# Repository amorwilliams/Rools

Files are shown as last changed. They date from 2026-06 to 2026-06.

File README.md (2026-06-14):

# Rools

10HP+2HP 可选扩展 Eurorack 多功能可视化 DSP 模块。Daisy Seed + 1.77" 横屏 IPS，单 App 运行模式。

## 文档索引

| 文档 | 说明 |
|---|---|
| [docs/00-overview.md](docs/00-overview.md) | 项目概述 |
| [docs/01-product-spec.md](docs/01-product-spec.md) | 产品规格 |
| [docs/02-panel-layout.md](docs/02-panel-layout.md) | 面板布局 |
| [docs/03-io-spec.md](docs/03-io-spec.md) | I/O 定义 |
| [docs/04-hardware-architecture.md](docs/04-hardware-architecture.md) | 硬件架构 |
| [docs/05-software-architecture.md](docs/05-software-architecture.md) | 软件架构 |
| [docs/06-ui-ux.md](docs/06-ui-ux.md) | 交互规范 |
| [docs/07-roadmap.md](docs/07-roadmap.md) | 开发里程碑 |
| [docs/08-app-switching.md](docs/08-app-switching.md) | App 丝滑切换 |
| [docs/decisions/](docs/decisions/) | ADR 决策记录（含电源/显示/机械） |
| [docs/references/modules-comparison.md](docs/references/modules-comparison.md) | 参考模块对比 |

## 快速开始

```bash
git clone --recursive <repo>
./build.sh          # 编译
./build.sh flash    # 刷机（Seed DFU 模式）
```

详见 [firmware/README.md](firmware/README.md)。

## 依赖版本（git submodule，固定 tag）

| 库 | Tag | Commit |
|----|-----|---|
| [libDaisy](https://github.com/electro-smith/libDaisy) | **v8.1.0** | `9498417` |
| [DaisySP](https://github.com/electro-smith/DaisySP) | **V1.0.0** | `a0494a3` |

克隆务必带 submodule：`git clone --recursive`。升级依赖时在 `lib/` 内 checkout 新 tag，编译验证后 commit 父仓库的 submodule 指针。

## 目录结构

```
Rools/
├── lib/            # libDaisy / DaisySP submodule
├── docs/           # 设计文档
├── hardware/       # 面板规格、BOM（KiCad 后续）
├── firmware/       # libDaisy 固件
└── build.sh        # 编译脚本
```

## 参考

- [Daisy Seed](https://daisy.audio/hardware/Seed/)
- [O_C 4.1 O.R.N.8](https://modulargrid.net/e/tunefish-modular-ornament-crime-o-c-t4-1-o-r-n-8)

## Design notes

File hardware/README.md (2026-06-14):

# hardware/

## 子目录

| 路径 | 内容 |
|---|---|
| [kicad/rools-core/](kicad/rools-core/) | **M2** KiCad 工程（10HP Core） |
| [panel/rools-core-10hp-spec.md](panel/rools-core-10hp-spec.md) | 10HP 面板开孔/丝印 |
| [panel/rools-exp-2hp-spec.md](panel/rools-exp-2hp-spec.md) | 2HP Exp 面板 |
| [bom/bom-draft.md](bom/bom-draft.md) | 初步 BOM |

## KiCad

打开 `hardware/kicad/rools-core/rools-core.kicad_pro`（KiCad 10.x）。

层次：`Power` / `Seed` / `Audio` / `CV` / `UI` — 不含 Exp（USB/MIDI）。

音频/电源对照 Daisy Patch Rev8，见 [kicad/rools-core/docs/patch-reference.md](kicad/rools-core/docs/patch-reference.md)。

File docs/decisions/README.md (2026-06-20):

# ADR 索引

Architecture Decision Records — 记录已确认的设计决策。

| ID | 标题 | 状态 |
|----|---|---|
| [ADR-001](ADR-001-single-app-mode.md) | 单 App 运行模式 | 已接受 |
| [ADR-002](ADR-002-display-choice.md) | 1.77" 横屏 IPS | 已接受 |
| [ADR-003](ADR-003-io-topology-10hp-exp.md) | 10HP + 2HP Exp 拓扑 | 已接受 |
| [ADR-004](ADR-004-ac-dc-coupling.md) | AC/DC 耦合策略 | 已接受 |
| [ADR-006](ADR-006-ext-4ch-dac.md) | 外置 4ch DAC | 已接受 |
| [ADR-007](ADR-007-usb-a-host-storage.md) | USB-A Host 存储 | 已接受 |
| [ADR-008](ADR-008-usb-ota-updater.md) | USB OTA 固件更新 | 已接受 |
| [ADR-009](ADR-009-center-button.md) | 双 Enc 中间单键 | 已接受 |
| [ADR-010](ADR-010-mono-stereo-normaling.md) | Mono/Stereo 与 Normalled | 已接受 |
| [ADR-011](ADR-011-power-supply.md) | 内部 Buck 电源与 USB 限流 | 已接受 |
| [ADR-012](ADR-012-display-spi-dma.md) | 显示 SPI DMA 与局部刷新 | 已接受 |
| [ADR-013](ADR-013-mechanical-depth.md) | 模块深度与机械布局 | 已接受 |
| [ADR-014](ADR-014-pcb-4-layer.md) | 4 层 PCB 叠层与分区 | 已接受 |
| [ADR-015](ADR-015-settings-persistence.md) | 设置持久化与 Flash 磨损策略 | 已接受 |
| [ADR-016](ADR-016-onboard-audio-no-pcm3060.md) | 板载音频（无 PCM3060） | 已接受 |
| [ADR-017](ADR-017-split-adc-knob-cv-sum.md) | CV/Knob 分路 ADC + 软件合成 | 已接受 |

## 如何新增 ADR

1. 复制模板：`ADR-XXX-简短标题.md`
2. 填写 Context / Decision / Consequences
3. 更新本索引

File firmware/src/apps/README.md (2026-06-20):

# App 开发规范

## 新增 App 步骤

1. 在 `apps/` 下创建 `my_app.h` / `my_app.cpp`
2. 继承 `rools::App`，实现全部纯虚函数
3. 在 `main.cpp`（或 `app_registry.cpp`）注册到 `AppShell`
4. 定义 `ParamMap` 标签（K1–K4 列语义）

## 示例骨架

```cpp
class SpectrumApp : public rools::App {
public:
    const char* name() const override { return "Spectrum"; }

    void on_enter() override {}
    void on_exit() override {}

    void audio_callback(const float* inL, const float* inR,
                        float* outL, float* outR, size_t n) override {
        // FFT / passthrough
    }

    void ui_draw() override {}

    const ParamMap* param_map() const override {
        static ParamMap m{"Gain", "Decay", "FFT Size", "Peak Hold"};
        return &m;
    }

    CouplingMode in_coupling() const override { return CouplingMode::DC; }
};
```

## 约束

- `audio_callback` 必须实时安全：无 malloc、无 blocking IO
- UI 在 `ui_draw` 或主循环低优先级刷新，目标 30 fps
- 读 `AppShell::columns[i].knob / .cv / .sum`（列语义由本 App 定义；见 `board/cv_reference.*`）
- 写 `AppShell::cv_out` 设置 CV A–D（由 shell 送 DAC）

## App 切换（MFX 式）

设计文档：[docs/08-app-switching.md](../../docs/08-app-switching.md)

| API | 线程 | 说明 |
|-----|---|---|
| `request_app_switch(i)` | UI | 运行时切换（TODO M3 fade） |
| `load_app(i)` | 任意 | 立即切换，仅 boot / 调试 |
| `uses_shared_dsp_memory()` | — | FX App 使用 `dsp_pool()` 时覆写 |
| `on_release_shared_memory()` | 音频 | pool Reset 前清尾音 |

```cpp
// TODO(M3) DelayApp 示例
bool uses_shared_dsp_memory() const override { return true; }
void on_release_shared_memory() override { /* 丢弃 delay 状态 */ }
```

## 路线图 App

| 文件（计划） | App |
|---|-----|
| `spectrum_app.*` | P0 |
| `oscilloscope_app.*` | P0 |
| `lissajous_app.*` | P1 |
| `delay_app.*` | P1 |
| `reverb_app.*` | P1 |
| `granular_app.*` | P2 |

## USB 依赖

Granular 等需 `HAS_EXP` 与 `UsbStorage`；无 U 盘时使用 Flash factory 样本。

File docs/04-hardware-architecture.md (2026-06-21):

# 04 — 硬件架构

## 系统框图

```
Front Panel (10HP)
├── 1.77" IPS ST7735 ── SPI ──► Daisy Seed
├── Enc A/B + Btn ────────────► GPIO
├── K1–K4 ──► MCP6004 ──► ADC4–7 (Knob)
├── CV1–4 Jacks ──► MCP6004 ──► ADC0–3 (CV)
├── CV A–D Jacks ◄── OPA4171 ◄── DAC8565 ◄── SPI1
└── IN/OUT Audio ──► TL074 ±10V ──► Seed pin 16–19 (板载 Codec)

Exp Panel (+2HP)
├── MIDI IN/OUT — USART1（D13/D14，Seed pin 14/15）→ P2 pin 7/8
└── USB-A Host ── OTG (D29–30, D0 ID) ──► P2 `+5V` + Exp 本地 VBUS 限流

Power: Eurorack ±12V → **Buck +5V** → Seed / Display / USB VBUS（限流）
       详见 [ADR-011](decisions/ADR-011-power-supply.md)
```

## 音频路径（无 PCM3060）

Eurorack jack ↔ **TL074**（×0.1 入 / ×10 出）↔ Seed **AUDIO_IN/OUT_L/R**（pin 16–19，板载 WM8731）。详见 [ADR-016](decisions/ADR-016-onboard-audio-no-pcm3060.md)。

## IN_R Normalled

IN_R jack **normalize 到 IN_L**，KiCad 网 **`IN_L_NORM`**（`J_CV_5` Tip ↔ `J_CV_6` Switch）。空插 R 时右声道 = 左声道。

接法详见 [ADR-010](decisions/ADR-010-mono-stereo-normaling.md)。

## Daisy Seed 引脚预算（2026-06 定稿）

**左侧 pin 1–19**

| 功能 | Daisy | Seed pin |
|---|---|---|
| Exp `EXP_GPIO0` | D0 | 1 | `USB_HS_ID` → P2 pin 15 |
| Enc A A/B/Sw | D1–D3 | 2–4 |
| Btn | D4 | 5 |
| 显示屏 SPI | D5–D10 | 6–11 | D8/D10 与 DAC8565 共用 |
| Exp I2C1 | D11–D12 | 12–13 | `I2C_SCL` / `I2C_SDA` → P2 pin 13/14 |
| Exp MIDI | D13–D14 | 14–15 | `MIDI_TX` / `MIDI_RX`（USART1）→ P2 pin 7/8 |
| Audio L/R In/Out | — | 16–19 |

**右侧 pin 22–32**

| 功能 | Daisy | Seed pin | ADC |
|---|---|---|-----|
| CV1–4 | D15–D18 | 22–25 | 0–3 |
| KNOB1–4 | D19–D22 | 26–29 | 4–7 |
| Enc B A/B/Sw | D23–D25 | 30–32 | — |
| DAC8565 | D26–D27 | 33–34 | `DAC_CS` / `DAC_LDAC` |
| 掉电检测 | D28 | 35 | net `EXTI_PWR` ← LM393（ADR-015） |

## ADC 分配

| 通道 | 用途 |
|---|---|
| ADC 0–3 | CV1–CV4（jack） |
| ADC 4–7 | KNOB1–K4 |
| ADC 8+ | — | D28 作掉电检测 GPIO，非 ADC 用途 |

固件在 AudioCallback 合成 `ControlColumn.sum`（[ADR-017](decisions/ADR-017-split-adc-knob-cv-sum.md)）。

## DAC

| 来源 | 用途 |
|---|---|
| DAC8565 ×4 | CV Out A–D（内部 2.5V 基准 → OPA4171 0–2.5V → ±10V；R 12.5k/100k 0.1%） |
| Seed 内置 DAC ×2 | v1 闲置 |

## P2 EXP_BUS（2×8，Core ↔ Exp）

| Pin | 信号 | 说明 |
|-----|---|---|
| 1 | `+3V3_D` | 数字域 |
| 2 | `+3V3_A` | Seed 模拟域（MIDI 光耦等） |
| 3 | `SWDIO` | 与 P3 并联，Exp 侧可选接 |
| 4 | `SWCLK` | |
| 5 | `RESET` | |
| 6 | `GND` | |
| 7 | `MIDI_TX` | D13 / Seed pin 14（USART1_TX） |
| 8 | `MIDI_RX` | D14 / Seed pin 15（USART1_RX） |
| 9 | `USB_D-` | D29 |
| 10 | `USB_D+` | D30 |
| 11 | `+5V` | Buck 输出；Exp USB Host 本地限流开关 |
| 12 | `GND` | |
| 13 | `I2C_SCL` | D11；Core 侧 4.7k→`+3V3_D` |
| 14 | `I2C_SDA` | D12 |
| 15 | `EXP_GPIO0` | D0 / `USB_HS_ID`；Exp Host 模式接 GND |
| 16 | `GND` | |

## 掉电检测

`+12V` → R43/R64 分压 → **LM393 U10A**（基准 `+3V3_D`）→ net **`EXTI_PWR`** → Seed **D28**。`+12V_SAFE`（D3 + C36/C37 ~2000 µF）维持 hold-up。阈值 ~10.6 V；固件 1 kHz 采样 debounce（连续 LOW ≥5 ms）→ 关背光 → Flash `Flush()`。详见 [ADR-015](decisions/ADR-015-settings-persistence.md)。

## 深度与机械

- 目标深度 **35 mm**（对齐 O_C 4.1）
- 1.77" 屏 + USB-A 为深度主要约束
- Core + Exp 同 PCB 侧出或 FFC 连接（KiCad 阶段定）
- 机械方案（Seed 贴片 / 沉板 USB / 矮排针）见 [ADR-013](decisions/ADR-013-mechanical-depth.md)

## PCB

- **4 层 / 1.6 mm**（[ADR-014](decisions/ADR-014-pcb-4-layer.md)）：L2 完整地、L3 电源；数字/模拟分区
- KiCad 工程后续置于 [hardware/](../hardware/)

## BOM 关键件（见 hardware/bom/bom-draft.md）

- Daisy Seed
- ST7735 1.77" IPS
- TL074 + MCP6004（音频/CV In 调理）
- DAC8565 + OPA4171（CV Out）
- USB-A 母座 + 5V Host 供电/限流（Exp）
- Thonkiconn 或 PJ398 插孔 ×12

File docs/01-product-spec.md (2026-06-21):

# 01 — 产品规格

## 外形

| 项目 | Rools Core | Rools Exp（可选） |
|---|---|---|
| 宽度 | 10 HP（~50.3 mm） | +2 HP（~10.16 mm） |
| 高度 | 3U（128.5 mm） | 同左 |
| 深度 | 目标 35–40 mm | 同核心 PCB |
| PCB | **4 层 1.6 mm** | [ADR-014](decisions/ADR-014-pcb-4-layer.md) |
| 面板 | 2 mm 阳极氧化铝 | 同左 |

## 显示

| 项目 | 规格 |
|---|---|
| 尺寸 | 1.77" IPS TFT |
| 方向 | 横屏（Landscape） |
| 分辨率 | 160 × 128 |
| 驱动 | ST7735（SPI） |
| Outline | 34.0 × 43.8 mm |

## 控件

| 控件 | 数量 |
|---|---|
| Encoder + Push | 2（Enc A / Enc B） |
| 小按键（6 mm tact） | 1（Enc 中间） |
| Potentiometer | 4（K1–K4） |

## I/O 汇总

| 类型 | 数量 |
|---|---|
| CV In | 4（CV1–CV4，DC）+ 4 Knob（K1–K4）分路 ADC，固件合成 |
| CV Out | 4（A–D，DAC8565 + OPA4171） |
| Audio In | 2（IN_L / IN_R，AC/DC 可选） |
| Audio Out | 2（OUT_L / OUT_R，AC/DC 可选） |
| MIDI | IN + OUT（Exp） |
| USB-A Host | 1（Exp） |

## 电气（预估，待实测）

| 项目 | 预估值 |
|---|---|
| +12V | 150–200 mA（Core）；+50–100 mA（Exp USB Host） |
| -12V | Seed 板载音频负轨（TL074 ±10V 调理） |
| +5V | **模块内部 Buck 自 +12V 产生**（不用机箱 +5V；禁线性 7805 主路径） |

电流预算与 USB 限流见 [ADR-011](decisions/ADR-011-power-supply.md)。

## MCU

| 项目 | 规格 |
|---|---|
| 模块 | Daisy Seed |
| MCU | STM32H750，480 MHz |
| RAM | 64 MB SDRAM |
| Flash | 8 MB |
| 音频 | 48 kHz / 24-bit（Seed 板载 Codec + TL074，[ADR-016](decisions/ADR-016-onboard-audio-no-pcm3060.md)） |

## 功能路线图

| 优先级 | App |
|---|-----|
| P0 | Spectrum Analyzer、Oscilloscope |
| P1 | Lissajous、Delay、Reverb |
| P2 | Granular、Envelope Follower |

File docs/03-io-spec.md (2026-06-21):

# 03 — I/O 规格

## 拓扑

**Core**：6 模拟输入（4 CV + 2 Audio）+ 6 模拟输出（4 CV + 2 Audio）  
**Exp**：MIDI ×2 + USB-A Host

## CV 输入（CV1–CV4）

| 项目 | 规格 |
|---|---|
| 方向 | 输入 |
| 耦合 | DC 固定 |
| 电压 | Eurorack ±10V（调理至 ADC 量程） |
| Knob | K1–K4 **分路 ADC**（D19–D22）；`sum` 固件合成（[ADR-017](decisions/ADR-017-split-adc-knob-cv-sum.md)） |
| 默认语义 | K1/K2 主参数；K3 Clock；K4 Trig（App 可重映射） |

## CV 输出（A–D）

| 项目 | 规格 |
|---|---|
| 方向 | 输出 |
| 耦合 | DC 固定 |
| 硬件 | DAC8565（SPI，4× 16-bit，内部 2.5V 基准）+ OPA4171 0–2.5V→±10V |
| 用途 | LFO / 包络 / Trig / Gate CV（App 分配） |

## 音频输入（IN_L / IN_R）

| 项目 | 规格 |
|---|---|
| 方向 | 输入 |
| 耦合 | 硬件 DC；软件 AC/DC 可选 |
| 电压 | Eurorack ±10V |
| **Mono** | **IN_R normalled 到 IN_L**（R 孔空 = R 通道 = L） |
| Codec | **Seed 板载**（pin 16–19）+ TL074 ±10V |

## 音频输出（OUT_L / OUT_R）

| 项目 | 规格 |
|---|---|
| 方向 | 输出 |
| 耦合 | 硬件 DC；软件 AC/DC 可选 |
| **Mono→立体声** | 软件 `out_R = out_L` |
| 菜单 | Input: Auto / Mono / Stereo；Output: Stereo / Mono(L→R) |

## 立体声 / Mono 实现分层

| 环节 | 层 | 做法 |
|---|-----|---|
| 只插 IN_L | 硬件 | IN_R normalled → IN_L |
| L 复制到 OUT_R | 软件 DSP | AudioEngine callback |

## Exp — MIDI

| 项目 | 规格 |
|---|---|
| 接口 | MIDI IN / OUT |
| 物理 | 3.5 mm TRS 或 DIN（待定） |
| 协议 | UART |

## Exp — USB-A Host

| 功能 | 路径 |
|---|---|
| 样本 | `/rools/samples/` |
| 预设 | `/rools/presets/` |
| Scene | `/rools/scenes/` |
| 固件 OTA | `/rools/_updater/*.bin` → 刷完删除，写 `update.log` |

## AC/DC 切换范围

| 接口 | 软件 AC/DC |
|---|---|
| IN_L / IN_R | ✅ |
| OUT_L / OUT_R | ✅ |
| CV1–CV4 | ❌ DC 固定 |
| CV A–D | ❌ DC 固定 |

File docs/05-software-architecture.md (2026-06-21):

# 05 — 软件架构

## 技术栈

- [libDaisy](https://daisy.audio/software/) + DaisySP
- C++17
- 48 kHz stereo audio callback（float，Seed 板载 24-bit）

## 单 App 模式

```
Boot → AppShell → AppMenu → [当前 App]
                              ↓
                    on_enter / process / on_exit
```

切换：Enc A 长按 → 选 App → 确认 → **~10 ms crossfade** → 新 App `on_enter()`。

丝滑切换设计详见 **[08-app-switching.md](08-app-switching.md)**（MFX 式：UI 递 flag、ISR fade、静态 DSP 池）。

## AppShell 职责

| 模块 | 职责 |
|---|---|
| AudioEngine | I/O、Mono 复制、AC/DC 高通、callback 分发 |
| UIRenderer | ST7735 菜单/波形/频谱；**SPI DMA + 局部刷新**（[ADR-012](decisions/ADR-012-display-spi-dma.md)） |
| IOMapper | 8 路 ADC（4 CV + 4 Knob）→ 4 列 `ControlColumn`（`knob`/`cv`/`sum` 软件合成） |
| CVRouter | CV A–D 输出分配 → `CvOutDriver`（DAC8565 SPI1 + LDAC） |
| ClockSync | CV3/CV4 边沿检测（App 可选） |
| UsbStorage | FAT32、样本/预设/OTA（HAS_EXP） |
| SettingsStore | `GlobalSettings` QSPI 环缓持久化；见 [ADR-015](decisions/ADR-015-settings-persistence.md) |

## 设置持久化

- `SettingsStore`：`Init` 读环缓 / 迁移旧格式 → RAM；`MarkDirty` + `Tick` 节流落盘；`Flush` 强制写
- CV 校准、切 App 等关键路径显式 `Flush`
- 掉电保存：D28 1 kHz debounce → 关背光 → `OnPowerFail()` / `Flush()`（[ADR-015](decisions/ADR-015-settings-persistence.md)）

## 输入采集约束（必须遵守）

- Encoder / Switch 的 `Debounce()` 必须在固定频率中断里执行（当前用 `AudioCallback`）。
- 中断里只做采集与累计：读取 `Increment()` 并累加到共享计数器，记录按下/抬起事件位。
- 主循环只做消费：原子读取并清零累计值，再分发到 `on_enc / on_btn`。
- 禁止在 UI 主循环里直接 `Debounce()`；SPI 刷屏会阻塞主循环，导致漏采样和手感变差。

## App 接口（见 firmware/src/app_shell.h）

```cpp
class App {
  virtual void on_enter() = 0;
  virtual void on_exit() = 0;
  virtual void audio_callback(float* inL, float* inR,
                              float* outL, float* outR, size_t n) = 0;
  virtual void ui_draw() = 0;
  virtual void on_encoder(Enc enc, int delta) {}
  virtual void on_button(Button btn) {}
  virtual const ParamMap* params() const = 0;
};
```

## 音频流

```
Seed onboard In (L,R) → [耦合/Mono] → App::audio_callback → [耦合/Mono out] → Seed onboard Out
                                      ↑
                              columns[0..3] knob/cv/sum（控制率，AudioCallback 更新）
```

## USB 目录（Exp）

```
/rools/
├── samples/
├── presets/
├── scenes/
├── _updater/     # rools_firmware.bin, update.log
└── README.html   # v2
```

## 条件编译

| 宏 | 含义 |
|----|---|
| `HAS_EXP` | 装 Exp：MIDI + USB Host |
| `HAS_USB` | 同 HAS_EXP |

## App 路线图

| 优先级 | App | 类型 |
|---|-----|---|
| P0 | SpectrumAnalyzer | 可视化 |
| P0 | Oscilloscope | 可视化 |
| P1 | Lissajous | 可视化 |
| P1 | Delay, Reverb | FX |
| P2 | Granular, EnvelopeFollower | FX / 工具 |

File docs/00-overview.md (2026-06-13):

# 00 — 项目概述

## 是什么

**Rools** 是一款 Eurorack 多功能模块：

- **10HP 核心**：大屏频谱/波形可视化 + DSP 效果器平台
- **+2HP 可选扩展**：MIDI + USB-A Host（样本/预设/固件更新）
- **MCU**：Electrosmith [Daisy Seed](https://daisy.audio/software/)

## 设计目标

1. **可视化优先** — 1.77" IPS 横屏，频谱/示波/李萨如
2. **平台化** — 统一 UI/I/O，单 App 模式增量扩展功能
3. **紧凑** — 10HP 核心对标 O_C 功能面宽度，大屏差异化

## 参考模块

| 模块 | 借鉴 |
|---|---|
| [O'Tools Plus](https://www.jonesvideo.com/otool/Otool_Plus_UserManual.pdf) | 测量/可视化 |
| [ALM MFX](https://www.busycircuits.com/alm017/) | 立体声 DSP FX |
| [O_C 4.1](https://modulargrid.net/e/tunefish-modular-ornament-crime-o-c-t4-1-o-r-n-8) | 10HP+2HP 架构、双 Encoder |
| [Instruō arbhar / Lúbadh](https://www.instruomodular.com/firmware/) | USB 样本/预设/OTA |

## 运行模式

**单 App**：一次运行一个功能（Spectrum / Delay / …），切换需退出当前 App。

## 术语

| 术语 | 含义 |
|---|---|
| HP | Horizontal Pitch，1 HP = 5.08 mm（面板宽约 50.3 mm @ 10HP） |
| CV | Control Voltage，控制电压 |
| Normalled | 插孔未接线时内部连通到另一孔（如 IN_R → IN_L） |
| App | 固件内一个独立功能模块 |

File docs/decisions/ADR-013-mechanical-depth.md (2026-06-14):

# ADR-013: 模块深度与机械布局

## 状态

已接受

## 背景

目标深度 **35–40 mm**（对齐 O_C 4.1）。主要堆叠：

- 前面板（2 mm Alu）+ 控件轴长
- 1.77" TFT + FPC/排针
- Daisy Seed（排母插接很占 Z 高度）
- Eurorack 插孔（Thonkiconn 筒深）
- Exp：**USB-A 母座** 为最大深度约束之一

## 决策

KiCad 阶段在以下方案中 **选最薄可行组合**（可混合）：

| 约束 | 优先方案 | 备选 |
|---|---|---|
| Daisy Seed | **贴片焊接** 于主 PCB（最薄） | 1.27 mm 矮排针 + 无排母直插 |
| Seed 可维护性 | 若必须可拆：矮排母 + 侧面留测试点 | 牺牲 3–5 mm |
| USB-A（Exp） | **沉板式** 母座 或 **垂直子板**（Exp PCB 90° 相对 Core） | 标准竖插母座（最深，尽量避免） |
| 屏 | 排针/FPC 贴 PCB，背光常亮或 GPIO 控 | — |
| Pot / Enc | 选 **薄型** 轴（9 mm pot 已选） | — |

**深度预算**：Layout 前建 Excel/mm 叠层表，合计 ≤ 38 mm（留 2 mm 公差）。

## 理由

- 35 mm 内排母 + 标准 USB-A + 标准 Seed 叠放几乎不可能
- O_C 4.1 同档深度是产品对标；超标则难进浅箱

## 后果

- 贴片 Seed 降低现场换 MCU 便利性；调试靠 SWD + USB Micro
- Exp 垂直子板可能影响面板 USB 开口机械；Gerber 前 3D 装配验证
- `04-hardware-architecture.md` 深度节引用本 ADR

## 待验证

- [ ] KiCad 3D：Core / Core+Exp 总深度
- [ ] 最短 Eurorack 电源线 + 模块同时插入机箱
- [ ] 面板开孔与 USB-A 对齐（Exp）

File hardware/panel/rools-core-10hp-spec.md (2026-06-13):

# Rools Core — 10HP 面板规格

## 外形

| 项目 | 值 |
|---|-----|
| 宽度 | 10 HP = 50.3 mm（Doepfer 实际宽度 ~50.0 mm） |
| 高度 | 128.5 mm |
| 厚度 | 2 mm 铝 |
| 安装孔 | 上下各 1× M3（8–10 HP 标准） |

## 开孔区（自上而下）

### 1. 显示屏窗口

| 项目 | 值 |
|---|-----|
| 模块 | 1.77" IPS ST7735 |
| Outline | 34.0 × 43.8 mm（横屏：宽 43.8，高 34） |
| 建议窗口 | 比 outline 大 0.5 mm/边 |
| 位置 | 水平居中，距顶 ~8 mm |

### 2. Encoder + 按钮行（~34 mm 以下）

| 件 | 数量 | 孔径/说明 |
|----|---|---|
| Rotary Encoder | 2 | 6 mm 轴；Enc A 列 2，Enc B 列 3 附近 |
| Tact Switch | 1 | 6 mm；两 Encoder 中间 |
| 行高 | ~14 mm | |

### 3. Potentiometer 行

| 件 | 数量 | 说明 |
|----|---|---|
| 9 mm 或 16 mm 轴 Knob | 4 | 与 CV1–4 列对齐；轴间距 ~12.5 mm |
| 行高 | ~16 mm | |

### 4. 插孔区（3 行 × 4 列）

| 行 | 标签（丝印） | 孔 |
|----|---|-----|
| 1 | CV IN: CV1 CV2 CV3 CV4 | 4× 3.5 mm |
| 2 | CV OUT: A B C D | 4× 3.5 mm |
| 3 | AUDIO: IN_L OUT_L IN_R OUT_R | 4× 3.5 mm |

- 孔型：Thonkiconn/PJ398 标准 7.8 mm 安装孔
- 列 pitch：~12.5 mm（50.3 mm 四等分减边距）
- 行 pitch：~9–10 mm

## 丝印

- 顶：ROOLS
- 分区：CV IN / CV OUT / AUDIO
- Enc A / Enc B 可选

## PCB 对位

- 面板与 PCB 用 2× M3 尼龙柱或直接 PCB 装孔对齐
- 深度预算：屏 + 编码器 + 竖插 jack ≈ 35 mm

## 待 KiCad 验证

- [ ] 4× Knob 9 mm 轴间距与帽干涉
- [ ] 1.77" 屏 bezel 与 Encoder 行垂直间距
- [ ] Mounting hole 与 jack 无干涉

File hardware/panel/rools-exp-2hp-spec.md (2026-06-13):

# Rools Exp — 2HP 面板规格

## 外形

| 项目 | 值 |
|---|-----|
| 宽度 | 2 HP = 10.16 mm（实际 ~10.0 mm） |
| 高度 | 128.5 mm |
| 厚度 | 2 mm 铝 |

## 开孔（自上而下）

| 序号 | 件 | 说明 |
|---|-----|---|
| 1 | MIDI IN | 3.5 mm TRS 或 2× DIN（待定） |
| 2 | MIDI OUT | 同左 |
| 3 | USB-A 母座 | 垂直或 90° 出板；注意深度 |

## 丝印

- MIDI IN / MIDI OUT
- USB HOST

## 机械

- 与 Core PCB 同深度目标 35 mm
- USB-A 全尺寸为深度关键件；可选 90° 母座减深度
- Exp 与 Core 面板相邻安装，共享或 FFC 连接 Core PCB

## 电气连接

- Exp 不独立供电：排针/FFC 从 Core 取 5V Host 供电、MIDI UART、USB D+/D-

## 待定

- [ ] MIDI TRS Type A vs B 标注
- [ ] USB 母座型号（深度 vs 牢靠）

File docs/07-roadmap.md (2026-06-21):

# 07 — 开发里程碑

## 阶段总览

| 阶段 | 目标 | 产出 |
|---|---|---|
| **M0 设计** | 设计案 + 工程结构 | 本文档集 ✅ |
| **M1 原型** | Seed + 屏 + 音频 breadboard | Spectrum App 可运行 |
| **M2 面板** | PCB + 10HP Core（+可选 Exp） | 完整 I/O |
| **M3 FX** | Delay / Reverb App | 可演出 |
| **M4 抛光** | UI 动画、预设、校准 | v1.0 |

## M1 原型清单

- [x] Daisy Seed + libDaisy 工具链
- [x] ST7735 1.77" 横屏驱动（blocking SPI，M1 可接受）
- [ ] 外置 Codec breadboard（或 Patch 子板参考）
- [ ] FFT 频谱显示 30 fps
- [x] Enc A/B + 单键 UI 框架

## M2 硬件清单

- [x] KiCad 原理图 Core 页（Power Rev 0.2 / CV / Audio / UI / Seed；[ADR-011](decisions/ADR-011-power-supply.md) Buck + 掉电检测）
- [ ] KiCad PCB Layout（[ADR-014](decisions/ADR-014-pcb-4-layer.md) **4 层**）
- [ ] 10HP 面板 Gerber（[ADR-013](decisions/ADR-013-mechanical-depth.md) 深度预算）
- [ ] 2HP Exp 面板（可选）
- [ ] DAC8565 CV Out 校准
- [ ] IN_R normalled 验证（[ADR-010](decisions/ADR-010-mono-stereo-normaling.md)）
- [ ] 功耗实测（Core / Core+Exp / USB U 盘）

## M2 软件清单

- [ ] **ST7735 SPI DMA + 局部刷新**（[ADR-012](decisions/ADR-012-display-spi-dma.md)，P0）

## M3 软件清单

- [ ] AppShell 完整实现
- [ ] **App 丝滑切换**（[08-app-switching.md](08-app-switching.md)：`request_app_switch`、fade、DspMemoryPool）
- [ ] App 菜单 UI（Enc A 长按）
- [ ] Delay / Reverb（DaisySP）
- [ ] 预设 JSON 读写（Flash）
- [ ] CV 列映射 API

## M4 清单

- [ ] USB Host + FAT32
- [ ] OTA `_updater` 流程
- [ ] Granular + 样本加载
- [ ] 出厂校准与测试脚本

## 风险跟踪

| 风险 | ADR | 阶段 |
|---|-----|---|
| +5V 发热 / USB 500 mA | [ADR-011](decisions/ADR-011-power-supply.md) | M2 PCB |
| SPI 阻塞拖慢 UI | [ADR-012](decisions/ADR-012-display-spi-dma.md) | M2 固件 |
| 深度超标 | [ADR-013](decisions/ADR-013-mechanical-depth.md) | M2 机械 |
| 2 层 PCB 噪声 / USB | [ADR-014](decisions/ADR-014-pcb-4-layer.md) | M2 Layout |
| Normalled 接错 | [ADR-010](decisions/ADR-010-mono-stereo-normaling.md) | M2 验证 |

另见 [docs/decisions/](decisions/) 与各文档「待验证」项。

## 版本命名

- 固件：`rools_firmware_vX.Y.Z.bin`
- 文档：随 Git 版本

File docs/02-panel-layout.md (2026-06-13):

# 02 — 面板布局

## Rools Core（10HP × 128.5 mm）v1.5

```
┌────────────────────────────────────────┐
│      1.77" IPS Landscape 160×128       │  ~34mm
├────────────────────────────────────────┤
│  Enc A+Push    [Btn]    Enc B+Push     │  ~14mm
├────────────────────────────────────────┤
│  (K1)      (K2)      (K3)      (K4)    │  ~16mm
├────────────────────────────────────────┤
│  CV IN:  CV1    CV2    CV3    CV4       │
│  CV OUT:  A      B      C      D        │
│  AUDIO: IN_L  OUT_L  IN_R  OUT_R        │
└────────────────────────────────────────┘
              ← 50.3mm (10HP) →
```

## 垂直对齐

| 列 | 1 | 2 | 3 | 4 |
|----|---|---|---|---|
| Knob | K1 | K2 | K3 | K4 |
| CV In | CV1 | CV2 | CV3 | CV4 |
| CV Out | A | B | C | D |
| Audio | IN_L | OUT_L | IN_R | OUT_R |

## Rools Exp（+2HP）

```
┌──────────┐
│ MIDI IN  │
│ MIDI OUT │
│ USB HOST │
└──────────┘
```

## 尺寸约束

| 项目 | 数值 |
|---|---|
| 10HP 面板宽 | ~50.3 mm |
| 1.77" 屏 outline 宽 | 43.8 mm（横屏） |
| 屏侧余量 | ~3 mm/侧（放不下 O_C 式屏侧小键） |
| 4 列插孔 pitch | ~12.5 mm |
| 接口区 | 3 行 × 4 列 = 12 孔 |
| 控件+屏+孔总高约 | ~97 mm（128.5 mm 内可行） |

## 与 O_C 对照

| O_C 4.1 | Rools |
|---|---|
| 小 OLED + 屏侧 A/B/X/Y | 1.77" 横屏 + 中间单键 |
| 双 Encoder | 双 Encoder + Push |
| 2× Knob | 4× Knob |
| CV IN 8 / CV OUT 8 | CV IN 4 / CV OUT 4 |
| AUDIO 底行 | 同序 IN_L OUT_L IN_R OUT_R |

## 丝印建议

- 分区标题：`CV IN` / `CV OUT` / `AUDIO`
- Audio 底行顺序与 O_C 一致，便于用户 muscle memory
- CV Out 标签 A–D（或 OUT A–D）

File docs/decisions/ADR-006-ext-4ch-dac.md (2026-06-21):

# ADR-006: 外置 4 通道 CV DAC

## 状态

已接受（2026-06 修订：MCP4728 → DAC8565）

## 背景

面板 CV Out A–D 共 4 路；Daisy Seed 仅 2 路 12-bit 内置 DAC。

## 决策

v1 采用 **DAC8565**（SPI，4× 16-bit）；**AVDD=`+3V3_DAC`**、**IOVDD=`+3V3_D`**（内部 2.5V 基准，VREFL→GND）；经 **OPA4171**（R=12.5k/100k，增益 −8）调理至 Eurorack ±10V（DAC 0–2.5V → jack +10V～−10V）。Seed 内置 DAC 闲置。

| 信号 | Seed GPIO | Seed pin | 网表 |
|---|---|---|---|
| SPI1_SCK | D8 | 10 | 与 ST7735 共用 |
| SPI1_MOSI | D10 | 11 | 与 ST7735 共用 |
| DAC_CS (SYNC) | D26 | 33 | `DAC_CS` |
| DAC_LDAC | D27 | 34 | `DAC_LDAC` |

D11–D12 → Exp I2C；D13–D14 → Exp MIDI（USART1）。

## 理由

- 16-bit 优于 12-bit MCP4728，利于 CV 精度
- 与 LCD 共用 SPI1，独立 CS/LDAC，不占 I2C
- OPA4171 低功耗四运放，单芯片覆盖 4 路输出调理

## 后果

- 固件 `CvOutDriver` SPI 写 + LDAC 脉冲同步四路
- 需 CV Out 校准流程

## 待验证

- [ ] 四路 0V / ±10V 实测（M2）
- [ ] LDAC 批量更新无通道错位

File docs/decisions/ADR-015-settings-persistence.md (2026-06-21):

# ADR-015: 设置持久化与 Flash 磨损策略

## 状态

已接受

## 背景

Rools 需在 QSPI Flash 中持久化：

- CV 逐通道校准 (`GlobalSettings.cv[4]`)
- 上次打开的 App (`last_app_index`)
- 未来各 App / 菜单参数

Flash 物理特性：**最小擦除粒度 4KB**。无论修改 1 字节还是整扇区，一次 `Save` 消耗 **1 次扇区擦写寿命**（约 10 万次/扇区，IS25LP080D）。

Daisy Seed 面包板阶段**无**掉电保持电容，拔电瞬间无法可靠落盘；M2 PCB 已画比较器 + hold-up 前端（见 §3）。

## 决策

### 1. 统一 `GlobalSettings` 聚合 + `SettingsStore`

- 单块 RAM 工作副本；`MarkDirty()` + 2s 节流 `Tick()` 自动落盘
- 切 App、CV 校准完成时 `Flush()` 立即落盘
- 实现见 `firmware/src/settings/settings_store.{h,cpp}`

### 2. QSPI 环形缓冲区磨损均衡（本期）

- **10 槽 × 4KB** 轮转写入，sequence 单调递增，开机取最大有效槽
- 理论寿命 ≈ **10 万次 × 10 = 100 万次**擦写
- 无变化时跳过写入（`settings == persisted`）
- 一次性迁移旧 `libDaisy PersistentStorage` 单槽格式

### 3. 掉电检测保存（M2 PCB + 固件 debounce）

Power 页（Rev 0.2）已画掉电前端，Seed **D28 / pin 35** 接 net **`EXTI_PWR`**：

| 硬件 | 件 / 参数 | 作用 |
|---|---|---|
| 比较器 | **U10A LM393** | +12V 分压（R43 22k / R64 10k）vs `+3V3_D` 基准；开漏输出 + R65 10k 上拉 |
| 触发阈值 | ~**10.6 V** | \(V_{trip} = 3.3 \times 32/10\)；正常 +12V 时分压 ≈ 3.75 V，`EXTI_PWR` 高 |
| 保持 | **D3 SS34** → `+12V_SAFE` + **C36/C37 各 1000 µF** | 共 ~2000 µF，维持 Buck/比较器/写 Flash 窗口 |
| MCU 输入 | D28（`EXTI_PWR`） | 持续 LOW 表示掉电预警 |

**软件**（`firmware/src/board/pwr_fail.{h,cpp}`）：

- **1 kHz 定时器 ISR** 读 D28；连续 LOW ≥ **5 ms** 才认定掉电（过滤毛刺；面包板 D28 未接时不触发）
- 确认掉电后顺序：**`EmergencyBacklightOff()`**（GPIO 关背光，~30–50 mA）→ **`SettingsStore::OnPowerFail()`** → `Flush()`
- 禁止 SPI 刷屏 / DMA / audio 阻塞
- `HasPowerFailHardware()` → `true`（无编译宏；面包板靠 debounce 不误触）

M2 启用后可切换 **PowerFailOnly** 策略：运行期仅改 RAM，每次开关机 1 次擦写，与环形缓冲可叠加。

### 4. 演进路径（非本期）

1. 环形缓冲（本期）
2. 掉电 debounce 保存（M2 PCB + hold-up，见 [ADR-011](ADR-011-power-supply.md)）
3. 可选外挂 FRAM（高频序列器等）

## M2 掉电保存 hardware / 软件 checklist

- [x] 掉电前端原理图（LM393 + hold-up，Power 页 Rev 0.2）
- [ ] 保持电容容量：\(C \geq I_{hold} \cdot \Delta t / \Delta V\)（hold 电流、目标维持 ms、允许压降）
- [ ] 比较器阈值实测：+12V 跌至 ~10.6 V 前触发，Buck 仍可供电
- [x] D28 / `EXTI_PWR` 接线（Seed 页）；D13/D14 = Exp MIDI USART1
- [x] 固件：1 kHz debounce + 关背光 + `Flush()`
- [ ] 与环形缓冲联调：掉电写下一槽，sequence 递增

## 后果

- 原型/DIY：环缓 + 节流足够（每天 100 次保存 ≈ 27 年量级）
- 面包板拔电可能丢失未 Flush 的 `last_app_index` 等（2s 窗口内）；无 hold-up 时掉电保存不可用
- 校准 App 已显式 `Flush()`

## 相关

- [ADR-011](ADR-011-power-supply.md) — 电源架构与 hold-up
- [05-software-architecture.md](../05-software-architecture.md) — AppShell / Settings 集成

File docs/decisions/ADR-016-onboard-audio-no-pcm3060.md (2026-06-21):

# ADR-016: 板载音频（无 PCM3060）

## 状态

已接受

## 背景

原计划参考 Daisy Patch 使用外置 PCM3060 + SAI2。Core 原理图定稿改为 **Seed 板载 Codec**（pin 16–19）+ **TL074** Eurorack ±10V 调理，不装 PCM3060。

## 决策

1. 音频 I/O 走 Seed **AUDIO_IN/OUT_L/R**（板载 WM8731 路径，libDaisy 默认 `StartAudio`）。
2. Eurorack jack ↔ TL074（×0.1 入 / ×10 出）↔ Seed 16–19。
3. **不**使用 SAI2 接外置 Codec；D26–D27 作 DAC8565 `DAC_CS`/`DAC_LDAC`（CV Out 走 SPI1）。
4. IN_R **normalled** 经 `IN_L_NORM` 网（见 [ADR-010](ADR-010-mono-stereo-normaling.md)）。

## 理由

- 少一颗 Codec，BOM/布局更简单
- Seed 48 kHz 板载路径与现有固件 `AudioHandle` 一致
- Patch 的 ±10V 运放调理仍适用

## 后果

- Eurorack **jack 侧** DC ±10V；Seed 引脚边界仍为 **AC 耦合**（见 [ADR-004](ADR-004-ac-dc-coupling.md)）
- 示波器绝对 DC 电压测量优先用 CV ADC，非音频口
- 文档/BOM 删除 PCM3060；`kAudioFullScaleVolts` 按 ±1.8V line level 标定

## 待验证

- [ ] 实机：音频电平与噪声（M2）
- [ ] IN_R 空插时 R 通道 = L（示波器）

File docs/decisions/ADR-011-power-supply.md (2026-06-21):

# ADR-011: 内部电源与 USB Host 供电

## 状态

已接受

## 背景

Rools Core + Exp 负载包括：

| 子系统 | 典型 +5V 电流（估） |
|---|---|
| Daisy Seed | ~80–120 mA |
| ST7735 背光 | ~30–50 mA |
| 外置 Codec + 运放 | ~30–60 mA |
| DAC8565 + OPA4171 CV Out | ~10–20 mA |
| USB-A Host（U 盘） | ~50–100 mA 典型；规范上限 **500 mA** |

Eurorack 机箱 **+5V 轨往往很弱或不存在**；模块必须从 **+12V（及必要时 -12V）** 自产 +5V / +3.3V。

线性稳压（7805、LM1117 等）从 +12V 降压到 +5V：压差 ~7V × 300mA ≈ **2W+ 发热**，10HP 模块会烫手且不稳定。

## 决策

1. **+5V / +3.3V 一律用开关降压（Buck）**，禁止 7805 / LM1117 作为主 +5V 路径。
2. **不从 Eurorack 面板 +5V 取电**（若机箱有也仅作备用/debug，不纳入设计）。
3. **+12V 入口**：DC-DC Buck → +5V 母线 → Seed / 屏 / Codec 数字 / USB VBUS 开关。
4. **USB Host**：独立 **限流开关**（如 TPS20xx / AP2553 类，500 mA 可配置），带故障指示；U 盘未插时不向 VBUS 供电。
5. KiCad 阶段做 **电流预算表** 并留 **≥30% 裕量**；Exp 未装时 Core 单独测功耗。

### 参考器件（KiCad Power 页 Rev 0.2）

| 功能 | 器件 / 参数 |
|---|---|
| +12V → +5V | **TPS54302** Buck；FB R4=73.2 k / R2=10 k → **5.0 V** |
| +5V → +3.3V | **AP2112K-3.3** LDO → `+3V3_D` |
| DAC 模拟 | `+3V3_D` → 磁珠 → **`+3V3_DAC`**（DAC8565 AVDD） |
| 掉电 hold-up | **D3 SS34**：`+12V` → `+12V_SAFE`；**C36+C37** 各 1000 µF（共 ~2000 µF） |
| 掉电预警 | **LM393 U10A**：+12V 分压 vs `+3V3_D` → `EXTI_PWR` → Seed D28；阈值 ~10.6 V |
| USB VBUS | 限流 High-side switch + ESD |

掉电保存软件见 [ADR-015](ADR-015-settings-persistence.md)；Flush 前先 GPIO 关 ST7735 背光以节省 hold-up 电流。

## 理由

- 与 Daisy Patch / 商用 Eurorack 数字模块惯例一致
- USB Host 500 mA 峰值必须在 PCB 级可控，不能靠 Seed 裸供电
- 热设计在 35 mm 深度内无散热片空间

## 后果

- BOM 成本略高于线性方案；布局需 Buck 电感 + 足够铜皮
- `01-product-spec` 电流预估值须 M2 实测修订
- 见 [hardware/bom/bom-draft.md](../../hardware/bom/bom-draft.md) 电源行

## 待验证

- [ ] Core-only / Core+Exp 满载 +12V 电流（示波器 + 万用表）
- [ ] U 盘插入浪涌与 Buck 跌落
- [ ] 连续运行 30 min 外壳温升

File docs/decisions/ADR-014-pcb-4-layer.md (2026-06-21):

# ADR-014: 4 层 PCB 叠层与分区

## 状态

已接受

## 背景

Rools Core（+ 可选 Exp）单块或叠板 PCB 同时包含：

- **数字**：Daisy Seed（STM32H7）、ST7735 SPI、DAC8565 SPI、USB OTG Host、MIDI UART
- **模拟**：Eurorack ±10V 音频 In/Out、4× CV In/Out + 运放调理
- **电源**：[ADR-011](ADR-011-power-supply.md) Buck 开关降压（开关噪声、大电流回流）

2 层板无完整地平面，数字/模拟/电源难以分区；Buck 与 Codec/CV 邻域时易出现 hum、CV 噪声、USB 不稳定。同类模块（Daisy Patch、O_C、MFX）量产多采用 **4 层**。

10HP（~50 mm）布线密度高：12× 3.5 mm jack + 屏 + Seed + 电源，2 层需大量跳线式地线，layout 与调试成本高。

## 决策

1. **M2 正式 PCB 打样采用 4 层**，标准厚度 **1.6 mm**（不增加 [ADR-013](ADR-013-mechanical-depth.md) 深度预算）。
2. **不推荐 2 层作为量产方案**；仅当单块极低成本 Core-only 原型且接受更长调试周期时可例外。
3. **推荐叠层**（JLC / 常见 4L1.6 mm 工艺）：

| 层 | 用途 |
|----|---|
| L1（Top） | 元件面：Seed、Buck、屏接口、数字连接器；模拟 jack 靠板边 |
| L2 | **完整地平面 GND**（尽量不分割） |
| L3 | **+5V / +3.3V 铺铜** + 少量信号；Buck 输入/输出短路径 |
| L4（Bottom） | 信号、Eurorack 16-pin 电源、部分插孔 |

4. **分区原则**：
   - Buck、Seed、屏、USB：**数字区**；开关结与电感远离 Codec/CV 运放
   - Codec、CV In/Out 运放：**模拟区**；模拟地 AGND 于 L2 单点汇 DGND（星形/桥接，KiCad 定网表）
   - USB 差分对：L1 走线，**L2 完整地参考**，目标 ~90 Ω
   - I2S / SPI：短、直；不跨 analog 区上方长距离飞线

5. Exp 与 Core **同 4 层板** 或 FFC 连接子板；子板同样优先 4 层（含 USB Host）。

## 理由

- 连续 GND 平面是 Eurorack 音频/CV 底噪的基础
- Buck + USB 500 mA 需要低阻抗电源与回流路径
- 4 层小批量加价通常可接受（相对调试与返工成本）
- 1.6 mm 四板与双板等厚，不影响机箱深度

## 后果

- KiCad 项目设 4-layer stackup；fab 备注指定阻抗（USB）若代工厂支持
- BOM 中 PCB 成本略高于 2 层（见 [bom-draft.md](../../hardware/bom/bom-draft.md)）
- Layout 需明确 AGND/DGND 连接点（一处，靠近 Codec）

## 待验证

- [ ] 首版 PCB：空载 / 满载音频 THD+噪声与 CV 噪声
- [ ] USB U 盘连续读写 + 频谱 UI 同时运行
- [ ] Buck 开关频率谐波在音频带内是否可接受（必要时调整 L/C 或频率）

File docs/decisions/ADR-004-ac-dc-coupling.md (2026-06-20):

# ADR-004: AC/DC 耦合策略

## 状态

已接受

## 决策

| 接口 | 硬件 | 软件 |
|---|---|---|
| IN_L/R, OUT_L/R | **Eurorack jack 侧** DC ±10V（TL074）；Seed pin 16–19 边界 **AC 耦合** | AC/DC 可选（IIR 高通 ~1–20 Hz） |
| CV1–CV4, CV A–D | DC 耦合 | 固定 DC |

CV 输出必须 DC（1V/oct、包络等）。音频 FX 默认软件 AC；示波/频谱默认 DC。

## 理由

- 8HP/10HP 无空间做 per-jack 物理 AC/DC 开关
- O'Tools 类测量需 DC 输入
- 软件高通满足 FX 去 DC 偏置

## 后果

- `CouplingMode` 在 AudioEngine 与 App 默认值中实现
- 不做面板耦合开关

## 实现提醒（Seed 板载 + TL074）

- Eurorack **jack 侧**经 TL074 为 DC ±10V（[ADR-016](ADR-016-onboard-audio-no-pcm3060.md)）。
- Seed pin 16–19 仍为 **AC 耦合** line level（±1.8V 量级）。
- 这意味着 `IN_L/R` 适合看音频与波形形状，不适合判断慢速/静态 CV 的绝对偏置电压。
- 在 Scope 中：
  - `A IN (IN_L/R)`：可用于频率、相位、形状观察；
  - `CV ADC (CV1–CV4)`：用于绝对电平、单极/双极偏置判断。
- 若需在音频口上做绝对电压测量，需硬件级改动（DC 耦合前端），不能仅靠 UI 或 App 参数切换完成。

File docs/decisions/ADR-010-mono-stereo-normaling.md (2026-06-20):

# ADR-010: Mono / Stereo 与 Normalled

## 状态

已接受

## 背景

用户期望只插 IN_L 时 Mono，输出 L+R 均有声。

## 决策

| 环节 | 实现 |
|---|---|
| 输入 Mono | **硬件**：IN_R jack **normalled 到 IN_L** |
| 输出 L→R | **软件**：`AudioEngine` 中 `out_R = out_L`（Mono 模式） |
| 插线检测 | **不做**纯软件检测（标准 jack 无 sense） |

菜单：`Input: Auto / Mono / Stereo`；`Output: Stereo / Mono(L→R)`。

## 理由

- Eurorack 惯例用 normalled 解决 Mono in
- 输出复制必须 DSP，用户常要双路输出同一信号

## 后果

- PCB 需 **带 Switch 触点的 normalled jack**（见下）
- KiCad 阶段核对 footprint 与网表

## 硬件接法（Thonkiconn / PJ398SM）

KiCad 网 **`IN_L_NORM`**：

```
J_CV_5 (IN_L) Tip ──► TL074 / Seed Left In
J_CV_6 (IN_R) Tip ──► TL074 / Seed Right In
J_CV_5 (IN_L) Tip ──► J_CV_6 (IN_R) Switch  （net: IN_L_NORM）
```

- **IN_R 未插线**：Switch 闭合，IN_R 收到 IN_L 信号 → 右声道 = 左声道
- **IN_R 插入**：Switch 断开，IN_R 仅接收自己的 Tip
- **无需软件检测**；`MonoMode::Auto` 信任此硬件行为

Sleeve：按 Eurorack mono 惯例接地。

## 待验证

- [x] KiCad 网表：`IN_L_NORM`（J_CV_5 Tip ↔ J_CV_6 Switch）
- [ ] 示波器：空插 R 时 R 通道波形 = L
- [ ] 插入 R 后 R 独立

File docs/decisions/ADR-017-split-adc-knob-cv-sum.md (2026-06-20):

# ADR-017: CV / Knob 分路 ADC + 软件合成

## 状态

已接受

## 背景

原规格写 K1–K4 与 CV1–4 **硬件求和**后接 4 路 ADC（Patch 式）。Core 原理图改为 **8 路独立 ADC**（4 CV + 4 Knob），固件在 AudioCallback 合成 `ControlColumn.sum`。

## 决策

| 路 | Seed GPIO | Seed pin | 用途 |
|----|---|---|---|
| CV1–4 | D15–D18 | 22–25 | CV jack（MCP6004 调理） |
| KNOB1–4 | D19–D22 | 26–29 | K1–K4 pot |
| Enc B | D23–D25 | 30–32 | 不占 ADC |

固件：

- `AdcChannelConfig` ×8，顺序 CV1…4、KNOB1…4
- `knob`：ADC uni 0…1
- `cv`：`CvAdcToNormalized()`（±10V 标定）
- `sum`：`ClampBipolar(cv + (knob - 0.5f) * 2.f)`（M2 可调权重）

## 理由

- 原理图分路更清晰；校准可独立
- 仍暴露单列 `knob` / `cv` 供 App 选用

## 后果

- 修订 [03-io-spec.md](../03-io-spec.md)、[04-hardware-architecture.md](../04-hardware-architecture.md)
- [calibration_app](firmware) 仍仅 CV 四路；Knob trim 可后加

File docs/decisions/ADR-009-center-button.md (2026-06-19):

# ADR-009: 双 Encoder 中间单键

## 状态

已接受

## 背景

曾考虑 O_C 式 A/B/X/Y 四小键；10HP + 1.77" 屏侧无余量。

## 决策

- **Enc A + Push**、**Enc B + Push**（仿 O_C 双 Encoder）
- **1× 6 mm tact** 置于两 Encoder 中间
- 取消 A/B/X/Y 四键

Btn 默认：Shift / 全屏 / 确认。

### 交互约定（补充）

- **Enc A 旋转**：选择参数（导航焦点）。
- **Enc B 旋转**：修改当前参数值。
- **Enc B 按压**：切换 `Coarse/Fine` 步进模式。
- **Oscilloscope 约定**：`Btn` 短按切 `Run/Stop`，`Shift + Enc B` 切 `Hold`。
- **Btn 短按**：App 级二级动作（如 Fullscreen / Hold / Toggle）。
- **Btn 长按（>220 ms）**：进入全局 `Shift` 按住态；松开即退出。
- **Shift + Enc A/B**：触发二级参数层或快捷功能（由 App 定义）。
- 非 Shift 时保持主路径一致：`Enc A` 导航、`Enc B` 参数、`Btn` 执行次动作。

### 优先级与冲突规则（固定）

- 菜单打开时，仅菜单消费输入，不透传 App。
- 菜单关闭时，`Shift + Enc` 优先于普通 `Enc`。
- 长按触发 Shift 后，释放 Btn 不再产生短按事件。
- 避免同帧双模式：`Enc A` 长按菜单与 Btn 长按 Shift 不叠加触发。

## 理由

- O_C 两 Encoder 中间单键已验证 UX
- 比四键省 3 GPIO，10HP 横向更宽松

## 后果

- App 快捷键少于 O_C，依赖 Enc 按压与 Btn 组合

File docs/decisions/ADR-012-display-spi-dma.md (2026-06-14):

# ADR-012: 显示 SPI 与 DMA 刷新

## 状态

已接受

## 背景

ST7735 横屏 160×128 RGB565：

- 全帧 ≈ **40 KB** SPI 数据
- 目标 UI **30 fps**（频谱 / 示波）
- 音频 **48 kHz** ISR 必须实时；**禁止在 audio callback 内 SPI 绘制**

M1 固件 `st7735.cpp` 使用 `BlockingTransmit` + 全屏 `Flush()`，breadboard 可接受；量产 UI 与 FX 并发时会占满主循环时间，并可能间接影响系统实时性。

## 决策

1. **线程模型**（已实现原则，保持）：
   - `audio_callback`：仅 DSP，无 SPI / malloc / blocking
   - `ui_draw`：主循环 ~30 fps，写 framebuffer
2. **SPI 传输**：M2 前升级为 **SPI DMA**（libDaisy `SpiHandle` DMA 或等价 HAL），CPU 提交 buffer 后返回。
3. **局部刷新**：频谱 / 示波只更新脏矩形（柱条区域 + 顶栏），避免每帧 40 KB 全屏。
4. **优先级**：DMA 传输期间 CPU 不得 busy-wait 整帧；可用双 buffer + 传输完成回调链式提交下一块。
5. **M1 例外**：breadboard 阶段允许 blocking SPI；M2 软件清单将 DMA 列为 **P0**。

### 数据流（目标）

```
ui_draw() → 写 framebuffer → FlushDirty(rect)
                              ↓
                         DMA SPI → ST7735
                              ↑
                    （与 audio ISR 无交集）
```

## 理由

- 40 KB × 30 fps ≈ 1.2 MB/s SPI + CPU 打包开销；blocking 模式在 H7 上勉强，FX App 加入后不够
- libDaisy 其他外设（ADC、UART）已广泛使用 DMA；SPI 有先例可参考
- 局部刷新在 M1 计划已预留 `SetAddrWindow()` API

## 后果

- `display/st7735.*` 需重构：DMA 状态机、`FlushRect()` 替代全屏 `Flush()`
- `spectrum_view` 可标记 dirty 列，减少带宽
- 文档 [05-software-architecture.md](../05-software-architecture.md) UIRenderer 行引用本 ADR

## 待验证

- [ ] DMA 刷新时测 audio callback 最大执行时间（应无劣化）
- [ ] 30 fps 频谱 + Delay 同时运行的 CPU 占用
- [ ] SPI 时钟上限（当前 PS_8 预分频，可酌情调快）

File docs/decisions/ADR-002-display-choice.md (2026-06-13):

# ADR-002: 1.77" 横屏 IPS 显示

## 状态

已接受

## 背景

8HP 只能竖屏 128×160；10HP 宽 50.3 mm 可横屏 160×128，频谱横向分辨率更好。

## 决策

- 面板 **10HP Core**
- **1.77" IPS**，ST7735，**横屏** 160×128
- Outline 43.8 × 34 mm

## 理由

- 频谱条横向更宽，产品核心差异化
- 比 O_C 小 OLED 可读性大幅提升
- 横屏比竖屏省 ~10 mm 面板高度给控件/插孔

## 后果

- 屏占满宽度，无法做 O_C 式屏侧小键
- UI 布局按宽屏重设计

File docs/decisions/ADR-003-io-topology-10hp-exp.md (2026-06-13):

# ADR-003: 10HP Core + 2HP Exp I/O 拓扑

## 状态

已接受

## 背景

参考 O_C 4.1：12HP = ~10HP 功能面 + 2HP MIDI/USB 扩展。

## 决策

**Core 10HP**：
- 4 CV In + 4 CV Out + 4 Audio（O_C 分层：CV 上、AUDIO 底）
- 2× Encoder + 1× Btn + 4× Knob

**Exp +2HP（可选）**：
- MIDI IN/OUT
- USB-A Host

## 理由

- 10HP 放 4 列插孔 pitch ~12.5 mm 可接受
- 数字接口不占核心功能面
- 用户可只购 Core

## 后果

- 固件 `#ifdef HAS_EXP`
- Core PCB 需预留 Exp 连接器

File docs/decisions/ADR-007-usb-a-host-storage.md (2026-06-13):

# ADR-007: USB-A Host 存储

## 状态

已接受

## 背景

Granular 等 App 需样本库；预设超出 Seed 8MB Flash；用户希望现场可编辑。

## 决策

Exp 面板 **USB-A Host**（非 USB-C），仿 [arbhar](https://www.instruomodular.com/wp-content/uploads/2023/12/arbhar-V2-Sample-Managment.pdf) / [Lúbadh](https://www.instruomodular.com/wp-content/uploads/2022/11/Lubadh-Manual-Firmare-V2-A5-.pdf)：

```
/rools/samples/
/rools/presets/
/rools/scenes/
```

首次插入自动初始化。WAV 48kHz/24bit 优先；预设 JSON。

## 理由

- USB-A 母座插 U 盘更牢靠，符合模块现场习惯
- O_C 4.1 同思路（USB HOST）
- Seed Micro USB 保留开发用，不占面板

## 后果

- +5V Host 供电与限流（~500 mA）
- 固件 FAT32 + USB Host 栈
- 无 Exp 时 Granular 等功能受限

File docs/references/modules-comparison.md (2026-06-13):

# 参考模块对比

## 总览

| 模块 | HP | 屏幕 | CV In | CV Out | Audio | 扩展 |
|---|-----|---|---|---|---|---|
| **Rools** | 10+2 | 1.77" IPS 160×128 | 4 | 4 | Stereo I/O | MIDI + USB-A |
| O_C 4.1 | 12 | OLED 128×64 | 8 | 8 | Stereo I/O | MIDI + USB-A/C |
| O'Tools Plus | 8 | OLED | — | — | I/O | — |
| ALM MFX | 6 | OLED | 3–7 | — | Stereo I/O | — |
| arbhar | 14+2 | LED | — | — | Stereo I/O | USB 样本/OTA |

## O_C 4.1

**借鉴**：10HP 功能面 + 2HP 数字扩展；双 Encoder；CV/AUDIO 分层；USB Host。

**差异**：Rools 大屏可视化；4+4 CV（非 8+8）；单 App（非 Quadrants 并行）。

## O'Tools Plus

**借鉴**：示波/频谱/测量；DC 耦合输入；AC/DC 软件切换思路。

**差异**：Rools 加 DSP FX 与 CV 平台；更大屏。

## ALM MFX

**借鉴**：紧凑立体声 FX；Clock/CV 调制；单功能深度。

**差异**：Rools 多 App 可切换；强可视化。

## arbhar / Lúbadh

**借鉴**：
- U 盘目录结构（samples / presets / scenes）
- `_updater` OTA
- preset.txt / JSON 人类可读

**差异**：Rools 非专用粒子机；USB 在 2HP Exp 非背板。

## Rools 定位一句话

**「带大屏的 O_C 式平台 + O'Tools 式测量 + MFX 式 FX，10HP 核心可装可扩。」**

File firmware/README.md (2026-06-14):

# firmware/

libDaisy + DaisySP 固件。

## 构建

需安装 [Daisy Toolchain](https://daisy.audio/software/)（`arm-none-eabi-gcc`、`dfu-util`）。

依赖在 `lib/` submodule。推荐在仓库根目录：

```bash
./build.sh          # 编译
./build.sh flash    # 编译 + 刷机
./build.sh clean    # 清理
```

或在 `firmware/` 下手动：

```bash
git submodule update --init --recursive
make -C ../lib/libDaisy
make -C ../lib/DaisySP
make
```

## 产物

| 文件 | 说明 |
|---|---|
| **`build/rools.bin`** | 最终固件，刷机 / OTA 用这个 |
| `build/rools.elf` | 调试用，含符号 |
| `build/rools.hex` | Intel HEX，Daisy 一般不用 |

## 刷机

`make program-dfu` 通过 `dfu-util` 将 `build/rools.bin` 写入 Daisy Seed。

1. Micro USB 连接 Seed
2. 按住 **BOOT**，再按 **RESET**（进入 DFU 模式）
3. 运行 `./build.sh flash` 或 `make program-dfu`

## IDE

`./build.sh` 编译成功后，若已安装 `compiledb`，会自动生成 `firmware/compile_commands.json`（供 clangd，已 gitignore）。

macOS 不要用 `pip3 install`（PEP 668 会报错），用 pipx：

```bash
brew install pipx
pipx ensurepath
pipx install compiledb
```

重开终端后 `./build.sh` 即可。不装也不影响编译，`.vscode/c_cpp_properties.json` 已覆盖基本 IntelliSense。

## 目录

```
src/
├── main.cpp       # 入口
├── app_shell.h    # App 接口与 AppShell
└── apps/          # 各 App 实现（后续）
```

## 配置

| 宏 | 含义 |
|----|---|
| `HAS_EXP` | 启用 MIDI + USB Host |

## USB 路径（HAS_EXP）

- `/rools/samples/`
- `/rools/presets/`
- `/rools/_updater/rools_firmware.bin`

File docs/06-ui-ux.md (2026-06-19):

# 06 — UI/UX 交互规范

## 控件默认行为

| 控件 | 默认 | App 可覆盖 |
|---|---|---|
| Enc A 旋转 | 选择当前参数 | 是 |
| Enc A 按压 | 确认 / 进入 | 是 |
| Enc B 旋转 | 修改当前参数值 | 是 |
| Enc B 按压 | 切换 Coarse / Fine | 是 |
| Btn（中）短按 | App 二级动作（Fullscreen/Hold/Toggle） | 是 |
| Btn（中）长按 | Shift（按住有效，松开退出） | 否（全局） |
| K1–K4 | 当前 App 第 1–4 列参数 | 语义随 App |
| CV1–CV4 | 叠加到 K1–K4 | 始终 |
| CV A–D | App 分配输出 | App 定义 |

## Knob ↔ CV 默认语义

| 列 | Knob | CV In | 典型 App 映射 |
|----|---|---|---|
| 1 | K1 | CV1 | 主参数 A（Time） |
| 2 | K2 | CV2 | 主参数 B（Feedback） |
| 3 | K3 | CV3 | Clock / Mod |
| 4 | K4 | CV4 | Trig / Mod |

App 切换时**物理列不变**，仅语义变。

## 显示模式

| 模式 | 内容 |
|---|---|
| Normal | 参数 + 小波形/频谱 |
| Fullscreen | 全屏波形 / 频谱 / 李萨如（Btn 或 Enc B 切换） |

## UI 布局架构（LayoutView）

### 分层职责

- `AppShell`：只负责输入时序、菜单状态路由、调用布局入口，不直接画 Top/Main/Bottom。
- `LayoutView`：统一控制 Top/Main/Bottom 绘制与分区刷新。
- `App`：只负责 Main 区内容绘制，通过 `ui_draw(const LayoutMetrics&)` 接收边界。

### 布局数据

`LayoutMetrics` 统一提供以下字段：

- `top_height`
- `bottom_height`
- `main_top`
- `main_bottom`
- `main_height`

### 渲染主流程

App 状态下统一走：

1. `DrawTopIfDirty(app)`
2. `app->ui_draw(layout)`
3. `DrawBottomIfDirty(app, shift_active)`
4. 分区 `FlushRect`（Top/Main/Bottom）

入口函数：`LayoutView::RenderAppFrame(App* app, bool shift_active)`。

### 菜单态约束

- 菜单打开时由菜单视图独占渲染。
- 进菜单/出菜单后执行 `LayoutView::ResetCache()`，确保回到 App 时 Top/Bottom 不残留脏缓存。

## Scope 交互（固定顺序4槽）

### 固定顺序路由策略

- 后台常驻采样 6 路输入：`Audio1`、`Audio2`、`CV1`、`CV2`、`CV3`、`CV4`。
- 前台固定 4 个显示槽位，不做补位重排。
- 路由优先级支持 `AudioFirst` / `CvFirst` 两种模式，且顺序固定：
  - `AudioFirst`：`T1=AIN1`、`T2=AIN2`、`T3=CV1`、`T4=CV2`
  - `CvFirst`：`T1=CV1`、`T2=CV2`、`T3=CV3`、`T4=CV4`
- 激活判定采用“GPIO优先 + ADC兜底”：
  - 有插座检测 GPIO 时，GPIO 作为真值来源；
  - 无 GPIO 时，使用短窗 `RMS/Peak` 阈值判定输入是否活跃。
- 路由切换带短保持（hysteresis + hold），降低插拔和噪声导致的跳轨。
- 任一槽位无信号时，槽位标签仍显示绑定接口名，仅通过颜色表达无信号状态。

### 单触发源规则

- 触发搜索只对 1 路执行（默认第一个可见槽位）。
- 其余已显示轨道共享同一个 `start_linear/subsample` 起点绘制。
- `AUTO`：无触发时自由运行；`NORM`：无触发时不绘制波形。

### 轨道选择与调参

- `Enc A` 旋转：切换焦点参数。
- `Enc B` 旋转：调整焦点参数值（作用于当前选中轨道）。
- `Enc A` 按下：选中上一条可见轨道。
- `Enc B` 按下：选中下一条可见轨道。
- `Shift + Enc B` 按下：切换 `Coarse/Fine` 步进。
- `Btn` 短按：`Hold/Unhold`。
- `Shift + Enc B` 旋转：`Hold/Unhold` 快捷切换。

### 渲染要求

- 4 轨同屏时自动走 Fast 路径（关闭 AA）以稳定帧率。
- 选中轨道高亮，非选中轨道降亮度。
- 底栏显示参数值（`B:<参数值>`，保留单位）。
- 无可见输入时主区域不显示文本提示（仅保留网格与状态栏信息）。

## Spectrum 高级交互

- 新增分析参数：`PeakTrack`、`Cursor`、`Freeze`（并保留 `Gain`/`Decay`/`FFT`/`PeakHold`）。
- `Enc A`：切换当前参数焦点；`Enc B`：调整当前焦点值。
- `Btn` 短按：`Freeze/Unfreeze`（冻结仅冻结分析画面，不中断音频直通）。
- `Shift + Enc B`：全屏切换。
- 视图覆盖层：
  - PeakTrack 开启时显示峰值频点标记线。
  - Cursor 开启时显示游标竖线；状态行显示 Peak/Cursor 的 `Hz + 归一化幅值`。
  - Freeze 开启时显示 `FREEZE` 标记。

## App 切换流程

1. Enc A 长按（>500 ms）→ App 菜单
2. Enc A 旋转选择
3. Enc A 短按确认
4. 交叉淡入淡出 50 ms → 新 App

## 菜单层级

```
[Fullscreen View] ← Btn
       ↑
[App Main UI] ← Enc B 返回
       ↑
[App Menu] ← Enc A 长按
       ↑
[Global Settings] ← 从 App Menu 进入（耦合、Mono、USB…）
```

## Shift 约定

- 长按 Btn（>220 ms）进入 Shift，松开退出。
- Shift 期间：`Enc A/B` 进入二级参数或快捷动作。
- 非 Shift 期间：保持主流程（A 导航、B 参数、Btn 次动作）。

## 手势优先级与冲突规则

- 菜单态优先：App 菜单打开时，手势仅供菜单消费，不透传到 App。
- Shift 次之：菜单关闭时，`Shift + Enc` 优先于普通 `Enc` 旋转。
- `CenterTap` 仅在短按时触发；长按进入 Shift 后，释放不会再触发短按。
- `Enc A` 长按开菜单与 `Btn` 长按进 Shift 相互独立，避免同帧双触发。

## 反馈

| 事件 | 反馈 |
|---|---|
| 参数变更 | 屏上数值更新；可选短促 UI 音（v2） |
| USB 刷固件 | 全屏「Updating…」+ 进度 |
| 错误 | 红色文字 + update.log |

## 无障碍 / 现场

- K1–K4 与 CV 列对齐，盲操可依赖列位置
- Encoder 负责精确数值，Knob 负责宏观扫参
- 全屏模式一键（Btn）便于远处查看频谱

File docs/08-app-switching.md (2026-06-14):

# 08 — App 丝滑切换（MFX 式）

> 参考：ALM MFX 多效果器切换无卡顿、无 Pop。Rools 多 App 切换目标对齐此体验。

## 现状（M1）

| 能力 | 状态 |
|---|---|
| 音频 ISR / UI 主循环分离 | ✅ 已实现 |
| `App` 基类 + `AppRegistry` | ✅ 已实现 |
| `load_app()` 立即切换 | ✅ 仅 `init()` 启动用 |
| UI 递 flag、音频侧切换 | 🔲 接口 `request_app_switch()` |
| Crossfade 防 Pop | 🔲 接口 `AppSwitchPhase` + `fade_gain_` |
| 共享 DSP 静态内存池 | 🔲 接口 `DspMemoryPool` |
| 参数保存 / 恢复 | 🔲 各 App static 实例暂保留；正式 `on_suspend` 后续 |

详见 `firmware/src/app_shell.h`、`firmware/src/dsp/dsp_memory_pool.h`。

## 目标架构

```
┌─────────────────┐         pending_index_          ┌──────────────────┐
│  UI Main Loop   │ ─── request_app_switch() ───► │  Audio ISR       │
│  Enc / 菜单     │         (只写 flag)            │  TickSwitch…()   │
│  ui_draw 30fps  │                               │  fade → Commit   │
└─────────────────┘                               └──────────────────┘
```

### 1. UI 与音频彻底分离

- **UI 线程**：读 Encoder、画菜单、调用 `request_app_switch(index)`，**不**直接改 `current_`。
- **音频 ISR**：每 buffer 开头 `TickSwitchStateMachine()`，见 flag 后自行完成切换。

### 2. Crossfade 消除 Pop

切换状态机：

```
Idle → FadingOut (~10 ms) → Switching → FadingIn (~10 ms) → Idle
```

- **FadingOut**：对输出乘 `fade_gain_` 1→0。
- **Switching**（静音点）：`on_exit()` → `DspMemoryPool::Reset()` → 换 App → `on_enter()`。
- **FadingIn**：`fade_gain_` 0→1。

默认 ~10 ms（48 kHz 下约 480 sample），可配置 `kSwitchFadeMs`。

### 3. 静态 DSP 内存池

Delay / Reverb 等 FX 需要大块 RAM，禁止 ISR 内 `malloc`。

- 开机分配 **一块最大 delay line**（`DspMemoryPool`，SDRAM）。
- 各 FX App 从 pool **bump 分配**，不 `free`。
- 切换 App 时 **`memset` 整池清零**，避免上一 App 尾音泄漏。
- 使用 pool 的 App 覆写 `uses_shared_dsp_memory()` / `on_release_shared_memory()`。

### 4. 状态保存与恢复

- 分析类 App（Spectrum）：参数存在 static 实例成员，切走再切回自然保留。
- FX App：必要时在 `on_exit()` 写 Flash preset 或 shell 侧 slot 表（M3+）。
- 菜单 UI：`AppRegistry::Name(i)` 列表 + Enc 选择 → `request_app_switch(i)`。

## 代码接口（已预留）

```cpp
// UI 线程
shell.request_app_switch(index);

// App 可选钩子
virtual bool uses_shared_dsp_memory() const;
virtual void on_release_shared_memory();

// 共享 RAM
DspMemoryPool pool;  // AppShell 成员，FX App 向 shell 申请
```

## 实现里程碑

| 阶段 | 任务 |
|---|---|
| **M2** | App 菜单 UI + `request_app_switch` 接线 |
| **M3** | Fade 状态机 + `CommitAppSwitch` 在 ISR 完成 |
| **M3** | `DspMemoryPool` 实现 + Delay/Reverb 接入 |
| **M4** | Preset JSON 与切换联动 |

## 与 ADR-001 关系

[ADR-001](decisions/ADR-001-single-app-mode.md) 单 App **运行**模式不变：同一时刻仍只有一个 App 占音频链；切换流程变丝滑，不是多 App 并行混音。

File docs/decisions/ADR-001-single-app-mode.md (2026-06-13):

# ADR-001: 单 App 运行模式

## 状态

已接受

## 背景

Rools 定位为多功能平台，需在 App 并行（如 O_C Quadrants）与单 App 之间选择。

## 决策

**一次只运行一个 App**。切换需退出当前 App（`on_exit` → `on_enter`），50 ms 音频 crossfade。

## 理由

- 初学者开发与调试更简单
- 10HP UI 不足以支撑多 App 并行状态显示
- Daisy Seed CPU 足够单 App 内 FFT + FX，但多 App 并行增加路由复杂度

## 后果

- 不能同时跑 Spectrum + Delay；用户需切换
- AppShell 接口清晰，后续可评估 v2 双 App 若硬件升级

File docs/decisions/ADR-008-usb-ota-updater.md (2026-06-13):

# ADR-008: USB OTA 固件更新

## 状态

已接受

## 背景

用户希望现场刷固件，无需 PC 线缆；参考 arbhar `_updater` 文件夹。

## 决策

U 盘路径 `/rools/_updater/rools_firmware.bin`：

1. 上电扫描
2. 发现 bin → 屏显 Updating → 写 Flash
3. **成功**：删除 bin；`update.log` 追加 OK 行
4. **失败**：保留 bin；log 追加 FAIL 原因
5. 重启

Micro USB（Seed 板载）作开发/救砖 fallback。

## 理由

- 与样本/预设共用 U 盘，目录隔离
- 用户流程：拷 bin → 插 U 盘 → 上电

## 后果

- Bootloader 或 early init 需 USB Host + FAT 支持
- bin 格式与 CRC 规范需在 M4 定稿

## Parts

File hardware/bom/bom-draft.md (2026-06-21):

# BOM 草案（M0）

> 非最终采购清单；封装/供应商 KiCad 阶段再定。

## 核心数字

|  Ref | 件 | 数量 | 备注 |
|---|-----|---|---|
| U1 | Daisy Seed | 1 | 64MB SDRAM 版 |
| U9 | DAC8565 | 1 | 4ch SPI DAC；内部 2.5V 基准；AVDD=`+3V3_DAC`，IOVDD=`+3V3_D` |
| U3 | ST7735 1.77" IPS | 1 | 160×128，SPI |
| — | STM32 USB Host PHY / 5V switch | 1 | 视 Seed OTG 设计 |

## 模拟 / 电源

|  Ref | 件 | 数量 | 备注 |
|---|-----|---|---|
| — | Eurorack 电源入口 | 1 | 16-pin 2×5 shrouded |
| — | **+12V → +5V Buck** | 1 | **TPS54302**（U2）；≥1 A；禁 7805/1117 主路径（[ADR-011](../../docs/decisions/ADR-011-power-supply.md)） |
| — | +5V → +3.3V LDO | 1 | **AP2112K-3.3** → `+3V3_D` |
| U10 | **LM393** 双比较器 | 1 | U10A 掉电检测 → `EXTI_PWR` / D28 |
| — | 掉电 hold-up | 2 | **1000 µF/25V**（C36/C37）+ **SS34**（D3）→ `+12V_SAFE` |
| — | USB VBUS 限流开关 | 1 | ~500 mA；Exp Host（[ADR-011](../../docs/decisions/ADR-011-power-supply.md)） |
| — | 运放 | 若干 | **TL074**（音频 ±10V）；**MCP6004**（CV In）；**OPA4171**（CV Out） |
| — | 精密电阻 0.1% | 12 | CV Out：**12.5k ×4**（R7/R9/R11/R13）+ **100k ×8**（R8/R10/R12/R14/R15–R18） |
| — | 保护/TVS | 若干 | CV/Audio 输入 |

## 控件

|  Ref | 件 | 数量 | 备注 |
|---|-----|---|---|
| — | Rotary Encoder w/ switch | 2 | |
| — | Tact 6×6 mm | 1 | 中间 Btn |
| — | 9 mm pot | 4 | K1–K4 |
| — | Knob 帽 | 6 | 2 Enc + 4 Pot |

## 连接器

|  Ref | 件 | 数量 | 备注 |
|---|-----|---|---|
| J1–J12 | 3.5 mm mono jack | 12 | Thonkiconn **PJ398SM** 等；IN_R Switch→IN_L Tip（[ADR-010](../../docs/decisions/ADR-010-mono-stereo-normaling.md)） |
| — | MIDI jack | 2 | Exp |
| — | USB-A 母座 | 1 | Exp；**沉板或垂直子板**（[ADR-013](../../docs/decisions/ADR-013-mechanical-depth.md)） |

## 面板 / 机械

|  Ref | 件 | 数量 | 备注 |
|---|-----|---|---|
| — | **PCB 4 层 1.6 mm** | 1 | [ADR-014](../../docs/decisions/ADR-014-pcb-4-layer.md)；JLC 等 |
| — | 10HP 面板 | 1 | 2 mm Alu |
| — | 2HP Exp 面板 | 1 | 可选 |
| — | M3 螺丝/柱 | 套 | |

## 预估 BOM 成本（粗略）

| 类别 | USD（估） |
|---|---|
| Daisy Seed | ~30 |
| 屏 + DAC8565 + OPA4171 | ~15–25 |
| 被动/运放/电源 | ~15–25 |
| 控件+孔 | ~20–30 |
| PCB+面板 | ~30–50 |
| **合计** | **~120–175**（单件原型） |

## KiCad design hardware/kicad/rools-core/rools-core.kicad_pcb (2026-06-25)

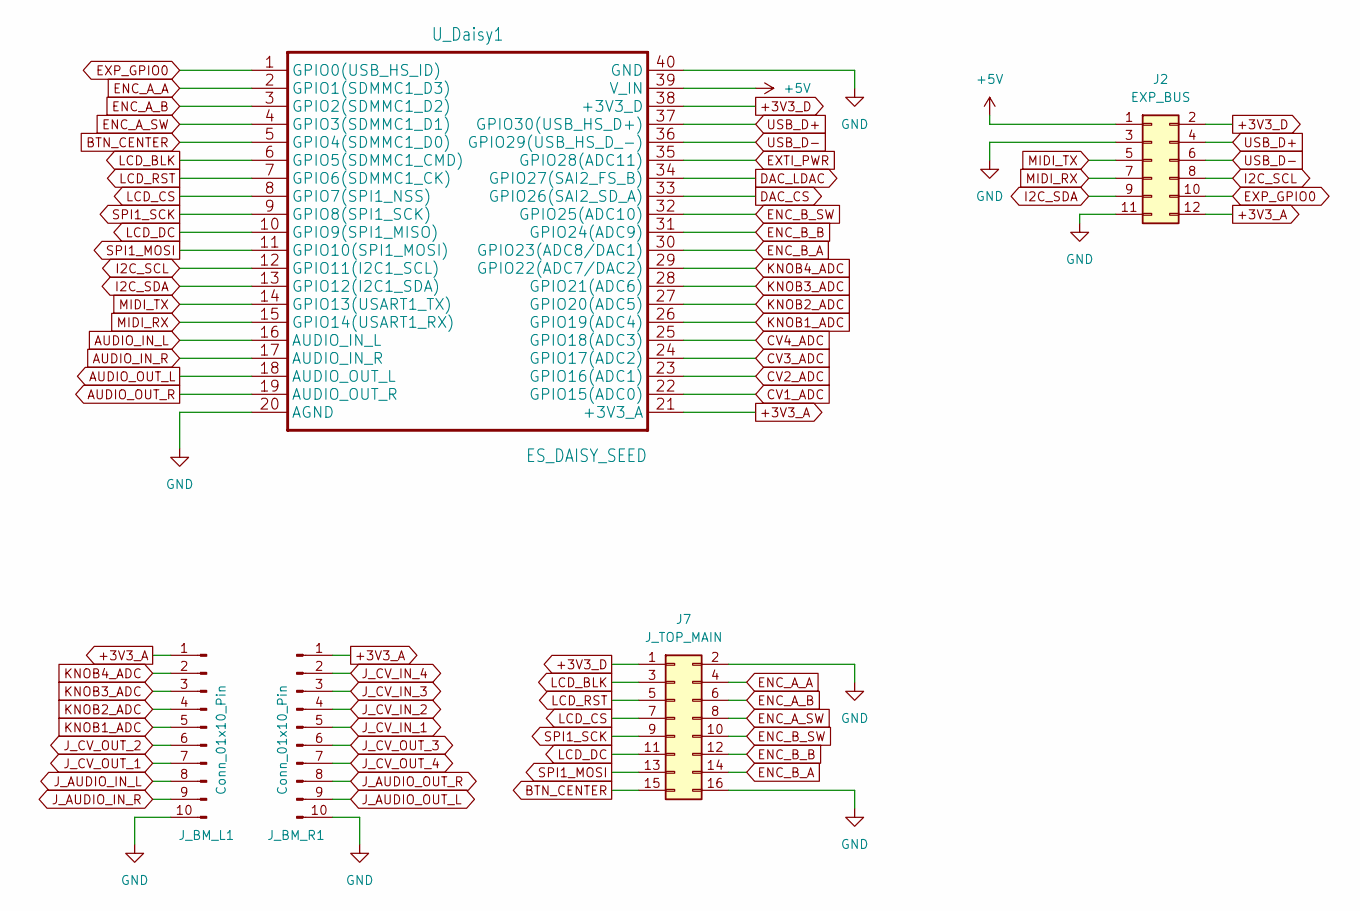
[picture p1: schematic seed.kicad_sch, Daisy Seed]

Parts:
J2: EXP_BUS; PinHeader_2x06_P2.54mm_Vertical
J7: J_TOP_MAIN; PinSocket_2x08_P2.54mm_Vertical_SMD
J_BM_L1: Conn_01x10_Pin; PinSocket_1x10_P2.54mm_Vertical
J_BM_R1: Conn_01x10_Pin; PinSocket_1x10_P2.54mm_Vertical
U_Daisy1: ES_DAISY_SEED; Electrosmith_Daisy_Seed

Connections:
+3V3_A: J2.12, J_BM_L1.1, J_BM_R1.1, U_Daisy1.21 (+3V3_A); also elsewhere on the board
+3V3_D: J2.2, J7.1, U_Daisy1.38 (+3V3_D); also elsewhere on the board
+5V: J2.1, U_Daisy1.39 (V_IN); also elsewhere on the board
AUDIO_IN_L: U_Daisy1.16 (AUDIO_IN_L); also elsewhere on the board
AUDIO_IN_R: U_Daisy1.17 (AUDIO_IN_R); also elsewhere on the board
AUDIO_OUT_L: U_Daisy1.18 (AUDIO_OUT_L); also elsewhere on the board
AUDIO_OUT_R: U_Daisy1.19 (AUDIO_OUT_R); also elsewhere on the board
BTN_CENTER: J7.15, U_Daisy1.5 (GPIO4(SDMMC1_D0)); also elsewhere on the board
CV1_ADC: U_Daisy1.22 (GPIO15(ADC0)); also elsewhere on the board
CV2_ADC: U_Daisy1.23 (GPIO16(ADC1)); also elsewhere on the board
CV3_ADC: U_Daisy1.24 (GPIO17(ADC2)); also elsewhere on the board
CV4_ADC: U_Daisy1.25 (GPIO18(ADC3)); also elsewhere on the board
DAC_CS: U_Daisy1.33 (GPIO26(SAI2_SD_A)); also elsewhere on the board
DAC_LDAC: U_Daisy1.34 (GPIO27(SAI2_FS_B)); also elsewhere on the board
ENC_A_A: J7.4, U_Daisy1.2 (GPIO1(SDMMC1_D3)); also elsewhere on the board
ENC_A_B: J7.6, U_Daisy1.3 (GPIO2(SDMMC1_D2)); also elsewhere on the board
ENC_A_SW: J7.8, U_Daisy1.4 (GPIO3(SDMMC1_D1)); also elsewhere on the board
ENC_B_A: J7.14, U_Daisy1.30 (GPIO23(ADC8/DAC1)); also elsewhere on the board
ENC_B_B: J7.12, U_Daisy1.31 (GPIO24(ADC9)); also elsewhere on the board
ENC_B_SW: J7.10, U_Daisy1.32 (GPIO25(ADC10)); also elsewhere on the board
EXP_GPIO0: J2.10, U_Daisy1.1 (GPIO0(USB_HS_ID))
EXTI_PWR: U_Daisy1.35 (GPIO28(ADC11)); also elsewhere on the board
GND: J2.3, J2.11, J7.2, J7.16, J_BM_L1.10, J_BM_R1.10, U_Daisy1.20 (AGND), U_Daisy1.40 (GND); also elsewhere on the board
I2C_SCL: J2.8, U_Daisy1.12 (GPIO11(I2C1_SCL))
I2C_SDA: J2.9, U_Daisy1.13 (GPIO12(I2C1_SDA))
IN_L_NORM: J_BM_L1.8; also elsewhere on the board
J_AUDIO_IN_R: J_BM_L1.9; also elsewhere on the board
J_AUDIO_OUT_L: J_BM_R1.9; also elsewhere on the board
J_AUDIO_OUT_R: J_BM_R1.8; also elsewhere on the board
J_CV_IN_1: J_BM_R1.5; also elsewhere on the board
J_CV_IN_2: J_BM_R1.4; also elsewhere on the board
J_CV_IN_3: J_BM_R1.3; also elsewhere on the board
J_CV_IN_4: J_BM_R1.2; also elsewhere on the board
J_CV_OUT_1: J_BM_L1.7; also elsewhere on the board
J_CV_OUT_2: J_BM_L1.6; also elsewhere on the board
J_CV_OUT_3: J_BM_R1.6; also elsewhere on the board
J_CV_OUT_4: J_BM_R1.7; also elsewhere on the board
KNOB1_ADC: J_BM_L1.5, U_Daisy1.26 (GPIO19(ADC4)); also elsewhere on the board
KNOB2_ADC: J_BM_L1.4, U_Daisy1.27 (GPIO20(ADC5)); also elsewhere on the board
KNOB3_ADC: J_BM_L1.3, U_Daisy1.28 (GPIO21(ADC6)); also elsewhere on the board
KNOB4_ADC: J_BM_L1.2, U_Daisy1.29 (GPIO22(ADC7/DAC2)); also elsewhere on the board
LCD_BLK: J7.3, U_Daisy1.6 (GPIO5(SDMMC1_CMD)); also elsewhere on the board
LCD_CS: J7.7, U_Daisy1.8 (GPIO7(SPI1_NSS)); also elsewhere on the board
LCD_DC: J7.11, U_Daisy1.10 (GPIO9(SPI1_MISO)); also elsewhere on the board
LCD_RST: J7.5, U_Daisy1.7 (GPIO6(SDMMC1_CK)); also elsewhere on the board
MIDI_RX: J2.7, U_Daisy1.15 (GPIO14(USART1_RX))
MIDI_TX: J2.5, U_Daisy1.14 (GPIO13(USART1_TX))
SPI1_MOSI: J7.13, U_Daisy1.11 (GPIO10(SPI1_MOSI)); also elsewhere on the board
SPI1_SCK: J7.9, U_Daisy1.9 (GPIO8(SPI1_SCK)); also elsewhere on the board
USB_D+: J2.4, U_Daisy1.37 (GPIO30(USB_HS_D+))
USB_D-: J2.6, U_Daisy1.36 (GPIO29(USB_HS_D_-))

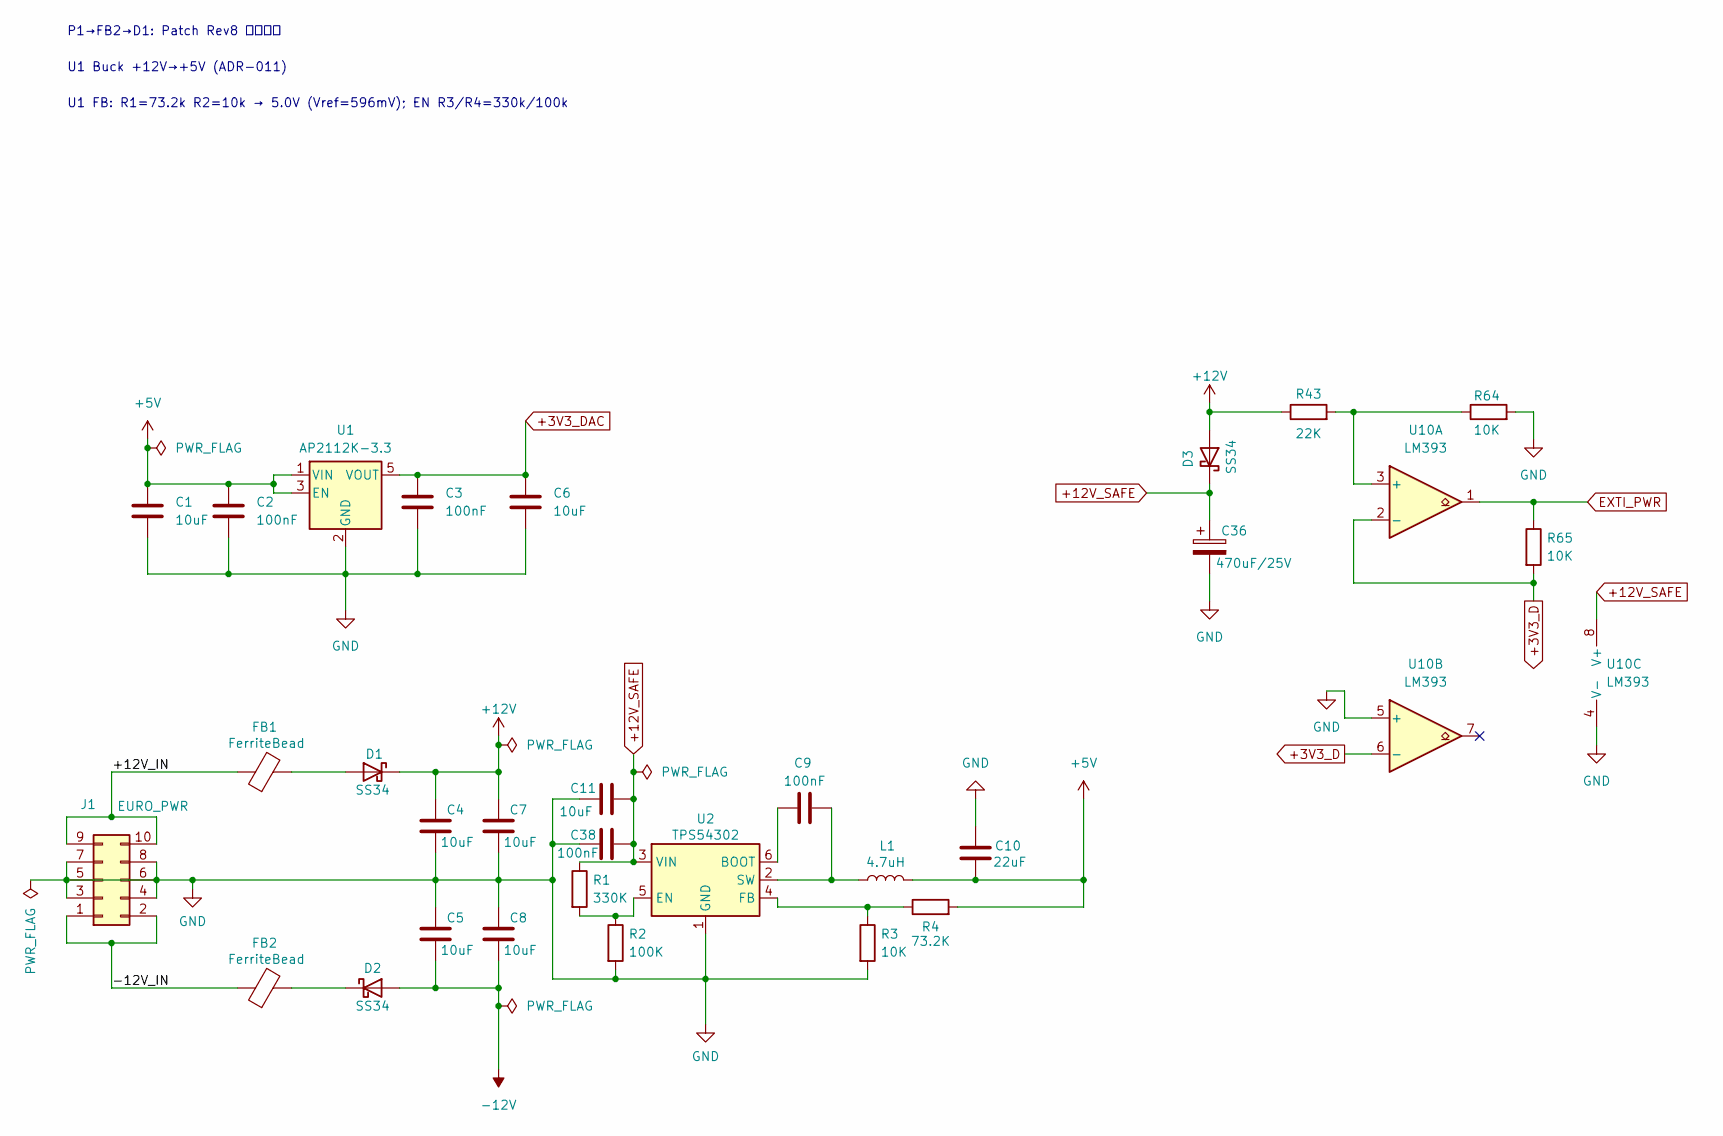
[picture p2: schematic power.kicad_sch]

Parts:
C1, C4, C5, C6, C7, C8, C11: 10uF; C_0603_1608Metric; LCSC C96446
C2, C3, C9, C38: 100nF; C_0603_1608Metric; LCSC C14663
C10: 22uF; C_0805_2012Metric; LCSC C45783
C36: 470uF/25V; CP_Radial_D8.0mm_P3.50mm; LCSC C43839
D1, D2, D3: SS34; D_SMA; LCSC C8678
FB1, FB2: FerriteBead; L_0603_1608Metric; LCSC C1015
J1: EURO_PWR; IDC-Header_2x05_P2.54mm_Vertical
L1: 4.7uH; L_Taiyo-Yuden_NR-40xx; LCSC C167208
R1: 330K; R_0603_1608Metric; LCSC C23137
R2: 100K; R_0603_1608Metric; LCSC C25803
R3, R64, R65: 10K; R_0603_1608Metric; LCSC C25804
R4: 73.2K; R_0603_1608Metric; LCSC C14890
R43: 22K; R_0603_1608Metric; LCSC C23162
U1: AP2112K-3.3; SOT-23-5; LCSC C51118
U2: TPS54302; TSOT-23-6; LCSC C311903
U10: LM393; SOIC-8_3.9x4.9mm_P1.27mm; LCSC C7955

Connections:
+3V3_D: R65.2, U10.2 (-), U10.6 (-); also elsewhere on the board
+3V3_DAC: C3.1, C6.1, U1.5 (VOUT); also elsewhere on the board
+5V: C1.1, C2.1, C10.1, L1.2, R4.2, U1.1 (VIN), U1.3 (EN); also elsewhere on the board
+12V: C4.1, C7.1, D1.1 (K), D3.2 (A), R43.1; also elsewhere on the board
+12V_SAFE: C11.1, C36.1, C38.2, D3.1 (K), R1.1, U2.3 (VIN), U10.8 (V+)
-12V: C5.2, C8.2, D2.2 (A); also elsewhere on the board
/Power/+12V_IN: FB1.1, J1.9, J1.10
/Power/-12V_IN: FB2.1, J1.1, J1.2
EXTI_PWR: R65.1, U10.1; also elsewhere on the board
GND: C1.2, C2.2, C3.2, C4.2, C5.1, C6.2, C7.2, C8.1, C10.2, C11.2, C36.2, C38.1, J1.3, J1.4, J1.5, J1.6, J1.7, J1.8, R2.2, R3.2, R64.2, U1.2 (GND), U2.1 (GND), U10.4 (V-), U10.5 (+); also elsewhere on the board
unnamed: D1.2 (A), FB1.2
unnamed: D2.1 (K), FB2.2
unnamed: C9.1, U2.6 (BOOT)
unnamed: R1.2, R2.1, U2.5 (EN)
unnamed: R3.1, R4.1, U2.4 (FB)
unnamed: C9.2, L1.1, U2.2 (SW)
unnamed: R43.2, R64.1, U10.3 (+)

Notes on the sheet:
P1→FB2→D1: Patch Rev8 反接保护
U1 Buck +12V→+5V (ADR-011)
U1 FB: R1=73.2k R2=10k → 5.0V (Vref=596mV); EN R3/R4=330k/100k

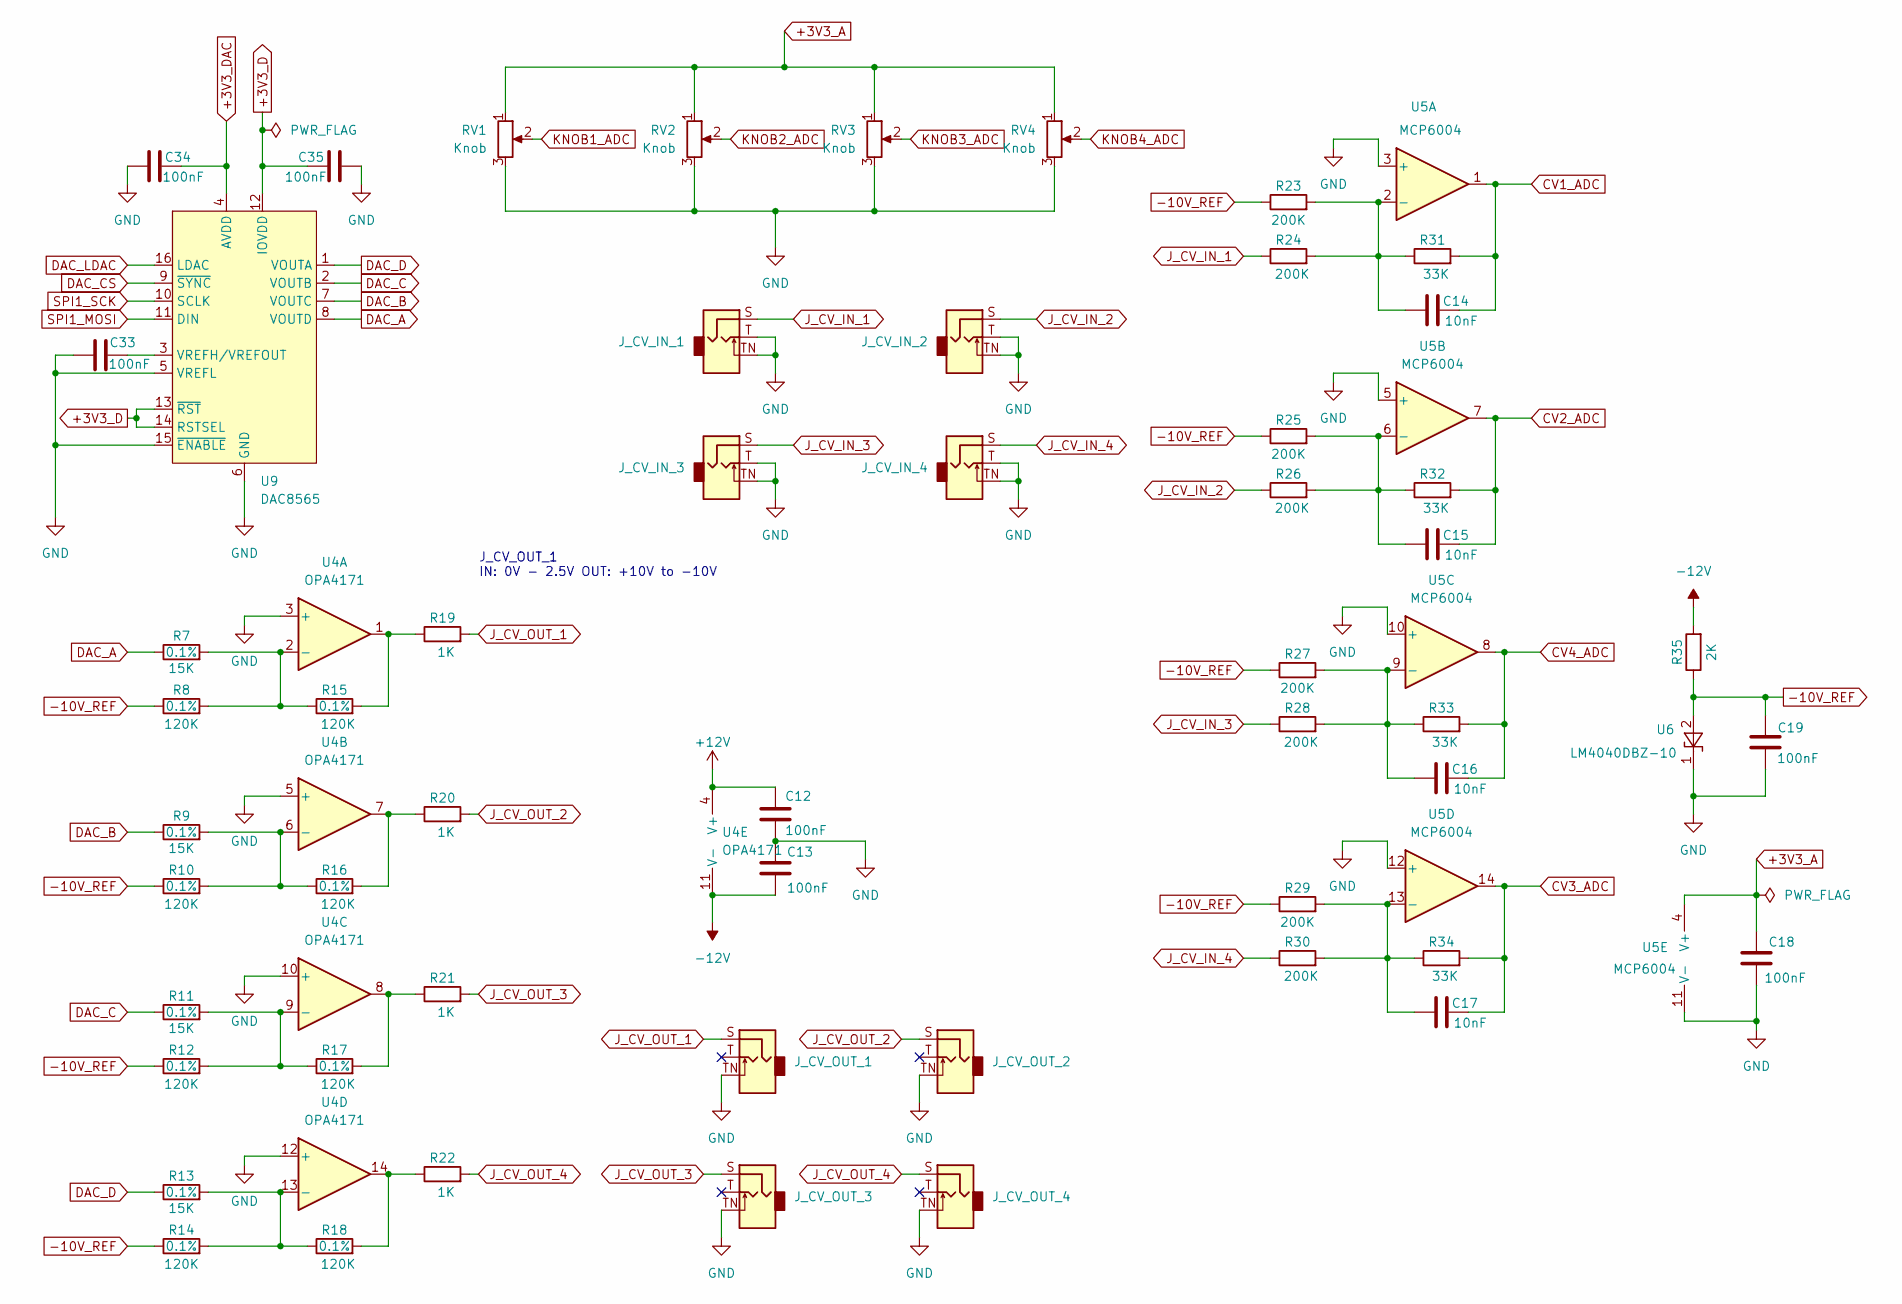
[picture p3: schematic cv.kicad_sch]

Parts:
C12, C13, C18, C19, C33, C34, C35: 100nF; C_0603_1608Metric; LCSC C14663
C14, C15, C16, C17: 10nF; C_0603_1608Metric; LCSC C1710
J_CV_IN_1, J_CV_IN_2, J_CV_IN_3, J_CV_IN_4: AudioJack2_SwitchT; Jack_3.5mm_QingPu_WQP-PJ398SM_Vertical_CircularHoles
J_CV_OUT_1, J_CV_OUT_2, J_CV_OUT_3, J_CV_OUT_4: AudioJack2_SwitchT; Jack_3.5mm_QingPu_WQP-PJ398SM_Vertical_CircularHoles
R7, R9, R11, R13: 15K; R_0603_1608Metric; Tolerance 0.1%; LCSC C326733
R8, R10, R12, R14, R15, R16, R17, R18: 120K; R_0603_1608Metric; Tolerance 0.1%; LCSC C136959
R19, R20, R21, R22: 1K; R_0603_1608Metric; LCSC C21190
R23, R24, R25, R26, R27, R28, R29, R30: 200K; R_0603_1608Metric; LCSC C728585
R31, R32, R33, R34: 33K; R_0603_1608Metric; LCSC C705768
R35: 2K; R_0603_1608Metric; LCSC C21194
RV1, RV2, RV3, RV4: Knob; RK09L_3pin_noMP
U4: OPA4171; SOIC-14_3.9x8.7mm_P1.27mm; LCSC C46269
U5: MCP6004; SOIC-14_3.9x8.7mm_P1.27mm; LCSC C7378
U6: LM4040DBZ-10; SOT-23; LCSC C201738
U9: DAC8565; TSSOP-16_4.4x5mm_P0.65mm; LCSC C69596

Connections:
+3V3_A: C18.1, RV1.1, RV2.1, RV3.1, RV4.1, U5.4 (V+); also elsewhere on the board
+3V3_D: C35.1, U9.12 (IOVDD), U9.13 (~RST), U9.14 (RSTSEL); also elsewhere on the board
+3V3_DAC: C34.1, U9.4 (AVDD); also elsewhere on the board
+12V: C12.2, U4.4 (V+); also elsewhere on the board
-10V_REF: C19.1, R8.1, R10.1, R12.1, R14.1, R23.1, R25.1, R27.1, R29.1, R35.1, U6.2 (A)
-12V: C13.1, R35.2, U4.11 (V-); also elsewhere on the board
CV1_ADC: C14.2, R31.2, U5.1; also elsewhere on the board
CV2_ADC: C15.2, R32.2, U5.7; also elsewhere on the board
CV3_ADC: C17.2, R34.2, U5.14; also elsewhere on the board
CV4_ADC: C16.2, R33.2, U5.8; also elsewhere on the board
DAC_A: R7.1, U9.8 (VOUTD)
DAC_B: R9.1, U9.7 (VOUTC)
DAC_C: R11.1, U9.2 (VOUTB)
DAC_CS: U9.9 (~SYNC); also elsewhere on the board
DAC_D: R13.1, U9.1 (VOUTA)
DAC_LDAC: U9.16 (LDAC); also elsewhere on the board
GND: C12.1, C13.2, C18.2, C19.2, C33.2, C34.2, C35.2, J_CV_IN_1.T, J_CV_IN_1.TN, J_CV_IN_2.T, J_CV_IN_2.TN, J_CV_IN_3.T, J_CV_IN_3.TN, J_CV_IN_4.T, J_CV_IN_4.TN, J_CV_OUT_1.TN, J_CV_OUT_2.TN, J_CV_OUT_3.TN, J_CV_OUT_4.TN, RV1.3, RV2.3, RV3.3, RV4.3, U4.3 (+), U4.5 (+), U4.10 (+), U4.12 (+), U5.3 (+), U5.5 (+), U5.10 (+), U5.11 (V-), U5.12 (+), U6.1 (K), U9.5 (VREFL), U9.6 (GND), U9.15 (~ENABLE); also elsewhere on the board
J_CV_IN_1: J_CV_IN_1.S, R24.1; also elsewhere on the board
J_CV_IN_2: J_CV_IN_2.S, R26.1; also elsewhere on the board
J_CV_IN_3: J_CV_IN_3.S, R28.1; also elsewhere on the board
J_CV_IN_4: J_CV_IN_4.S, R30.1; also elsewhere on the board
J_CV_OUT_1: J_CV_OUT_1.S, R19.2; also elsewhere on the board
J_CV_OUT_2: J_CV_OUT_2.S, R20.2; also elsewhere on the board
J_CV_OUT_3: J_CV_OUT_3.S, R21.2; also elsewhere on the board
J_CV_OUT_4: J_CV_OUT_4.S, R22.2; also elsewhere on the board
KNOB1_ADC: RV1.2; also elsewhere on the board
KNOB2_ADC: RV2.2; also elsewhere on the board
KNOB3_ADC: RV3.2; also elsewhere on the board
KNOB4_ADC: RV4.2; also elsewhere on the board
unnamed: R15.2, R19.1, U4.1
unnamed: R16.2, R20.1, U4.7
unnamed: R17.2, R21.1, U4.8
unnamed: R18.2, R22.1, U4.14
unnamed: R7.2, R8.2, R15.1, U4.2 (-)
unnamed: R9.2, R10.2, R16.1, U4.6 (-)
unnamed: R11.2, R12.2, R17.1, U4.9 (-)
unnamed: R13.2, R14.2, R18.1, U4.13 (-)
unnamed: C14.1, R23.2, R24.2, R31.1, U5.2 (-)
unnamed: C15.1, R25.2, R26.2, R32.1, U5.6 (-)
unnamed: C16.1, R27.2, R28.2, R33.1, U5.9 (-)
unnamed: C17.1, R29.2, R30.2, R34.1, U5.13 (-)
unnamed: C33.1, U9.3 (VREFH/VREFOUT)
SPI1_MOSI: U9.11 (DIN); also elsewhere on the board
SPI1_SCK: U9.10 (SCLK); also elsewhere on the board

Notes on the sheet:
J_CV_OUT_1 IN: 0V - 2.5V OUT: +10V to -10V

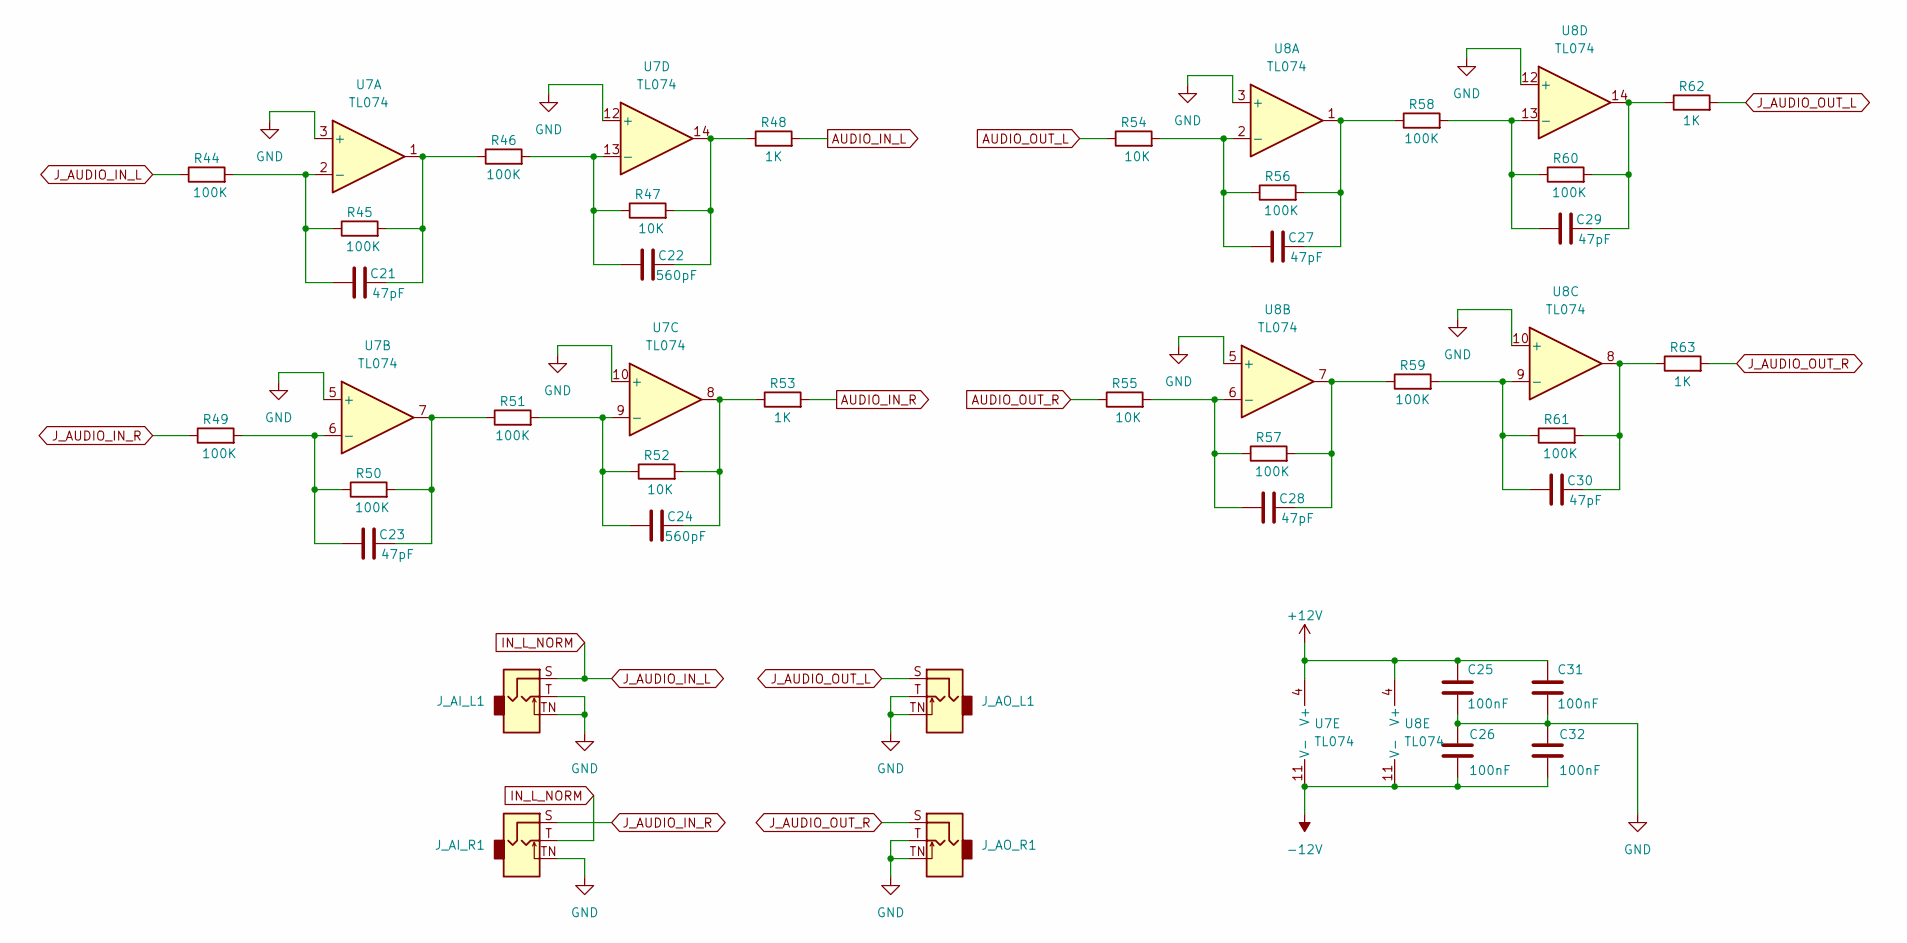
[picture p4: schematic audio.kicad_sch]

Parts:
C21, C23, C27, C28, C29, C30: 47pF; C_0603_1608Metric; LCSC C1653
C22, C24: 560pF; C_0603_1608Metric; LCSC C1680
C25, C26, C31, C32: 100nF; C_0603_1608Metric; LCSC C14663
J_AI_L1: AudioJack2_SwitchT; Jack_3.5mm_QingPu_WQP-PJ398SM_Vertical_CircularHoles
J_AI_R1: AudioJack2_SwitchT; Jack_3.5mm_QingPu_WQP-PJ398SM_Vertical_CircularHoles
J_AO_L1: AudioJack2_SwitchT; Jack_3.5mm_QingPu_WQP-PJ398SM_Vertical_CircularHoles
J_AO_R1: AudioJack2_SwitchT; Jack_3.5mm_QingPu_WQP-PJ398SM_Vertical_CircularHoles
R44, R45, R46, R49, R50, R51, R56, R57, R58, R59, R60, R61: 100K; R_0603_1608Metric; LCSC C25803
R47, R52, R54, R55: 10K; R_0603_1608Metric; LCSC C25804
R48, R53, R62, R63: 1K; R_0603_1608Metric; LCSC C21190
U7, U8: TL074; SOIC-14_3.9x8.7mm_P1.27mm; LCSC C6964

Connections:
+12V: C25.2, C31.2, U7.4 (V+), U8.4 (V+); also elsewhere on the board
-12V: C26.1, C32.1, U7.11 (V-), U8.11 (V-); also elsewhere on the board
AUDIO_IN_L: R48.2; also elsewhere on the board
AUDIO_IN_R: R53.2; also elsewhere on the board
AUDIO_OUT_L: R54.1; also elsewhere on the board
AUDIO_OUT_R: R55.1; also elsewhere on the board
GND: C25.1, C26.2, C31.1, C32.2, J_AI_L1.T, J_AI_L1.TN, J_AI_R1.TN, J_AO_L1.T, J_AO_L1.TN, J_AO_R1.T, J_AO_R1.TN, U7.3 (+), U7.5 (+), U7.10 (+), U7.12 (+), U8.3 (+), U8.5 (+), U8.10 (+), U8.12 (+); also elsewhere on the board
IN_L_NORM: J_AI_L1.S, J_AI_R1.T, R44.1; also elsewhere on the board
J_AUDIO_IN_R: J_AI_R1.S, R49.1; also elsewhere on the board
J_AUDIO_OUT_L: J_AO_L1.S, R62.2; also elsewhere on the board
J_AUDIO_OUT_R: J_AO_R1.S, R63.2; also elsewhere on the board
unnamed: C21.2, R45.2, R46.1, U7.1
unnamed: C22.2, R47.2, R48.1, U7.14
unnamed: C23.2, R50.2, R51.1, U7.7
unnamed: C24.2, R52.2, R53.1, U7.8
unnamed: C27.2, R56.2, R58.1, U8.1
unnamed: C28.2, R57.2, R59.1, U8.7
unnamed: C29.2, R60.2, R62.1, U8.14
unnamed: C30.2, R61.2, R63.1, U8.8
unnamed: C21.1, R44.2, R45.1, U7.2 (-)
unnamed: C23.1, R49.2, R50.1, U7.6 (-)
unnamed: C24.1, R51.2, R52.1, U7.9 (-)
unnamed: C22.1, R46.2, R47.1, U7.13 (-)
unnamed: C27.1, R54.2, R56.1, U8.2 (-)
unnamed: C28.1, R55.2, R57.1, U8.6 (-)
unnamed: C30.1, R59.2, R61.1, U8.9 (-)
unnamed: C29.1, R58.2, R60.1, U8.13 (-)

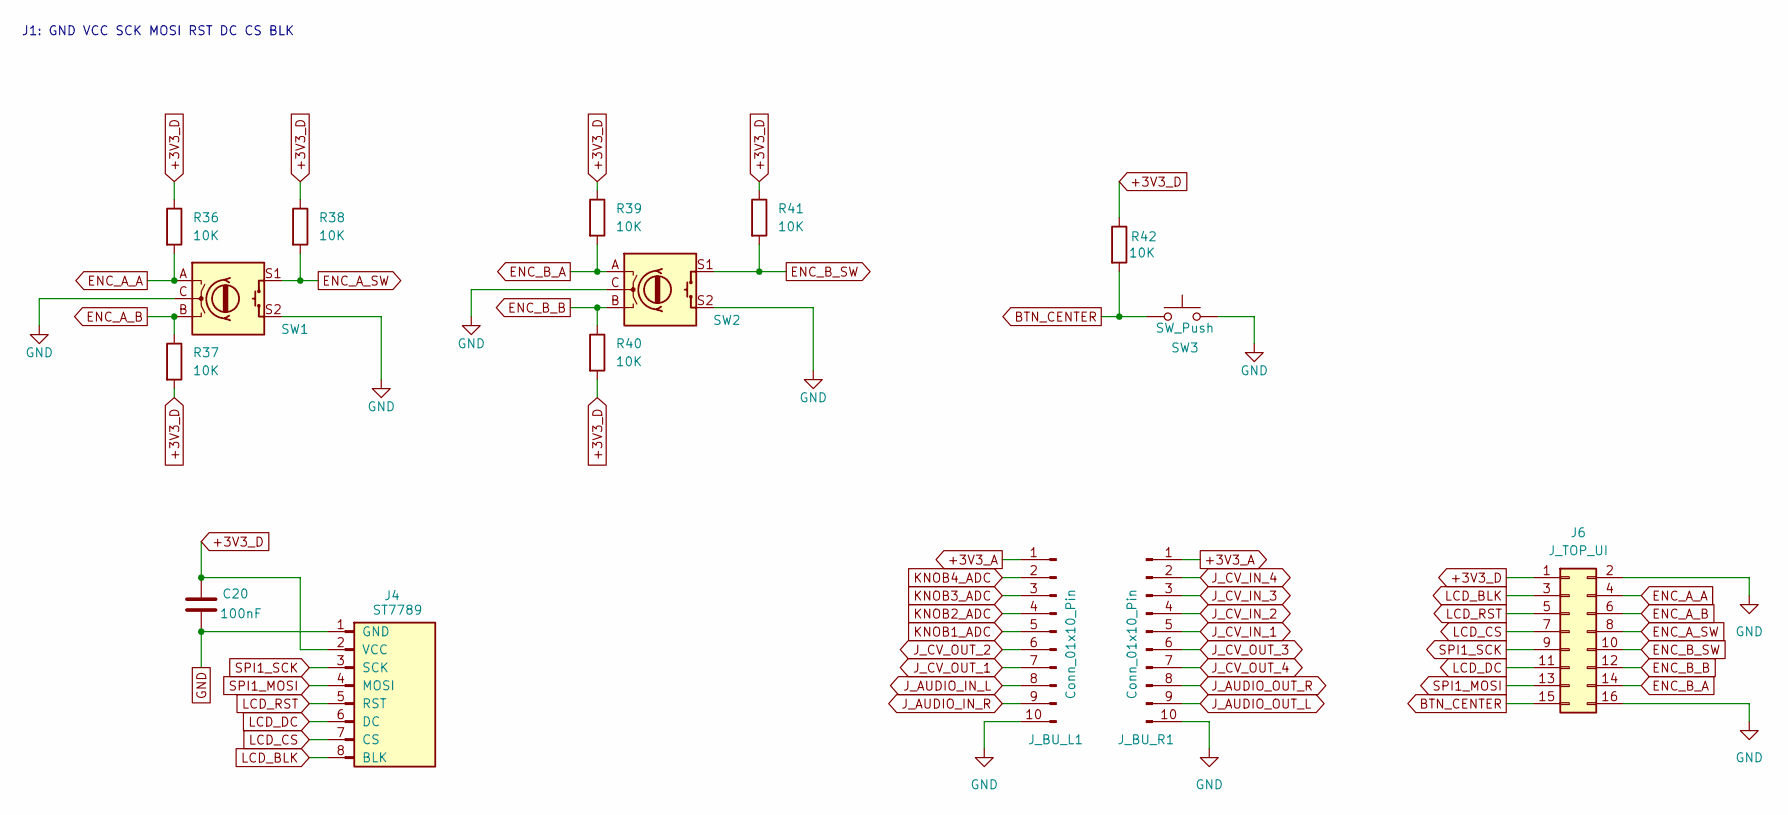
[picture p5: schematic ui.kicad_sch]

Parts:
C20: 100nF; C_0603_1608Metric; LCSC C14663
J4: ST7789; Display_1.54in_240x240
J6: J_TOP_UI; PinHeader_2x08_P2.54mm_Vertical
J_BU_L1: Conn_01x10_Pin; PinHeader_1x10_P2.54mm_Vertical
J_BU_R1: Conn_01x10_Pin; PinHeader_1x10_P2.54mm_Vertical
R36, R37, R38, R39, R40, R41, R42: 10K; R_0603_1608Metric; LCSC C25804
SW1, SW2: RotaryEncoder_Switch; RotaryEncoder_Alps_EC11E-Switch_Vertical_H20mm
SW3: SW_Push; SW_PUSH_6mm

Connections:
+3V3_A: J_BU_L1.1, J_BU_R1.1; also elsewhere on the board
+3V3_D: C20.1, J4.2 (VCC), J6.1, R36.1, R37.2, R38.1, R39.1, R40.2, R41.1, R42.1; also elsewhere on the board
BTN_CENTER: J6.15, R42.2, SW3.1; also elsewhere on the board
ENC_A_A: J6.4, R36.2, SW1.A; also elsewhere on the board
ENC_A_B: J6.6, R37.1, SW1.B; also elsewhere on the board
ENC_A_SW: J6.8, R38.2, SW1.S1; also elsewhere on the board
ENC_B_A: J6.14, R39.2, SW2.A; also elsewhere on the board
ENC_B_B: J6.12, R40.1, SW2.B; also elsewhere on the board
ENC_B_SW: J6.10, R41.2, SW2.S1; also elsewhere on the board
GND: C20.2, J4.1 (GND), J6.2, J6.16, J_BU_L1.10, J_BU_R1.10, SW1.C, SW1.S2, SW2.C, SW2.S2, SW3.2; also elsewhere on the board
IN_L_NORM: J_BU_L1.8; also elsewhere on the board
J_AUDIO_IN_R: J_BU_L1.9; also elsewhere on the board
J_AUDIO_OUT_L: J_BU_R1.9; also elsewhere on the board
J_AUDIO_OUT_R: J_BU_R1.8; also elsewhere on the board
J_CV_IN_1: J_BU_R1.5; also elsewhere on the board
J_CV_IN_2: J_BU_R1.4; also elsewhere on the board
J_CV_IN_3: J_BU_R1.3; also elsewhere on the board
J_CV_IN_4: J_BU_R1.2; also elsewhere on the board
J_CV_OUT_1: J_BU_L1.7; also elsewhere on the board
J_CV_OUT_2: J_BU_L1.6; also elsewhere on the board
J_CV_OUT_3: J_BU_R1.6; also elsewhere on the board
J_CV_OUT_4: J_BU_R1.7; also elsewhere on the board
KNOB1_ADC: J_BU_L1.5; also elsewhere on the board
KNOB2_ADC: J_BU_L1.4; also elsewhere on the board
KNOB3_ADC: J_BU_L1.3; also elsewhere on the board
KNOB4_ADC: J_BU_L1.2; also elsewhere on the board
LCD_BLK: J4.8 (BLK), J6.3; also elsewhere on the board
LCD_CS: J4.7 (CS), J6.7; also elsewhere on the board
LCD_DC: J4.6 (DC), J6.11; also elsewhere on the board
LCD_RST: J4.5 (RST), J6.5; also elsewhere on the board
SPI1_MOSI: J4.4 (MOSI), J6.13; also elsewhere on the board
SPI1_SCK: J4.3 (SCK), J6.9; also elsewhere on the board

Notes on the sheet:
J1: GND VCC SCK MOSI RST DC CS BLK

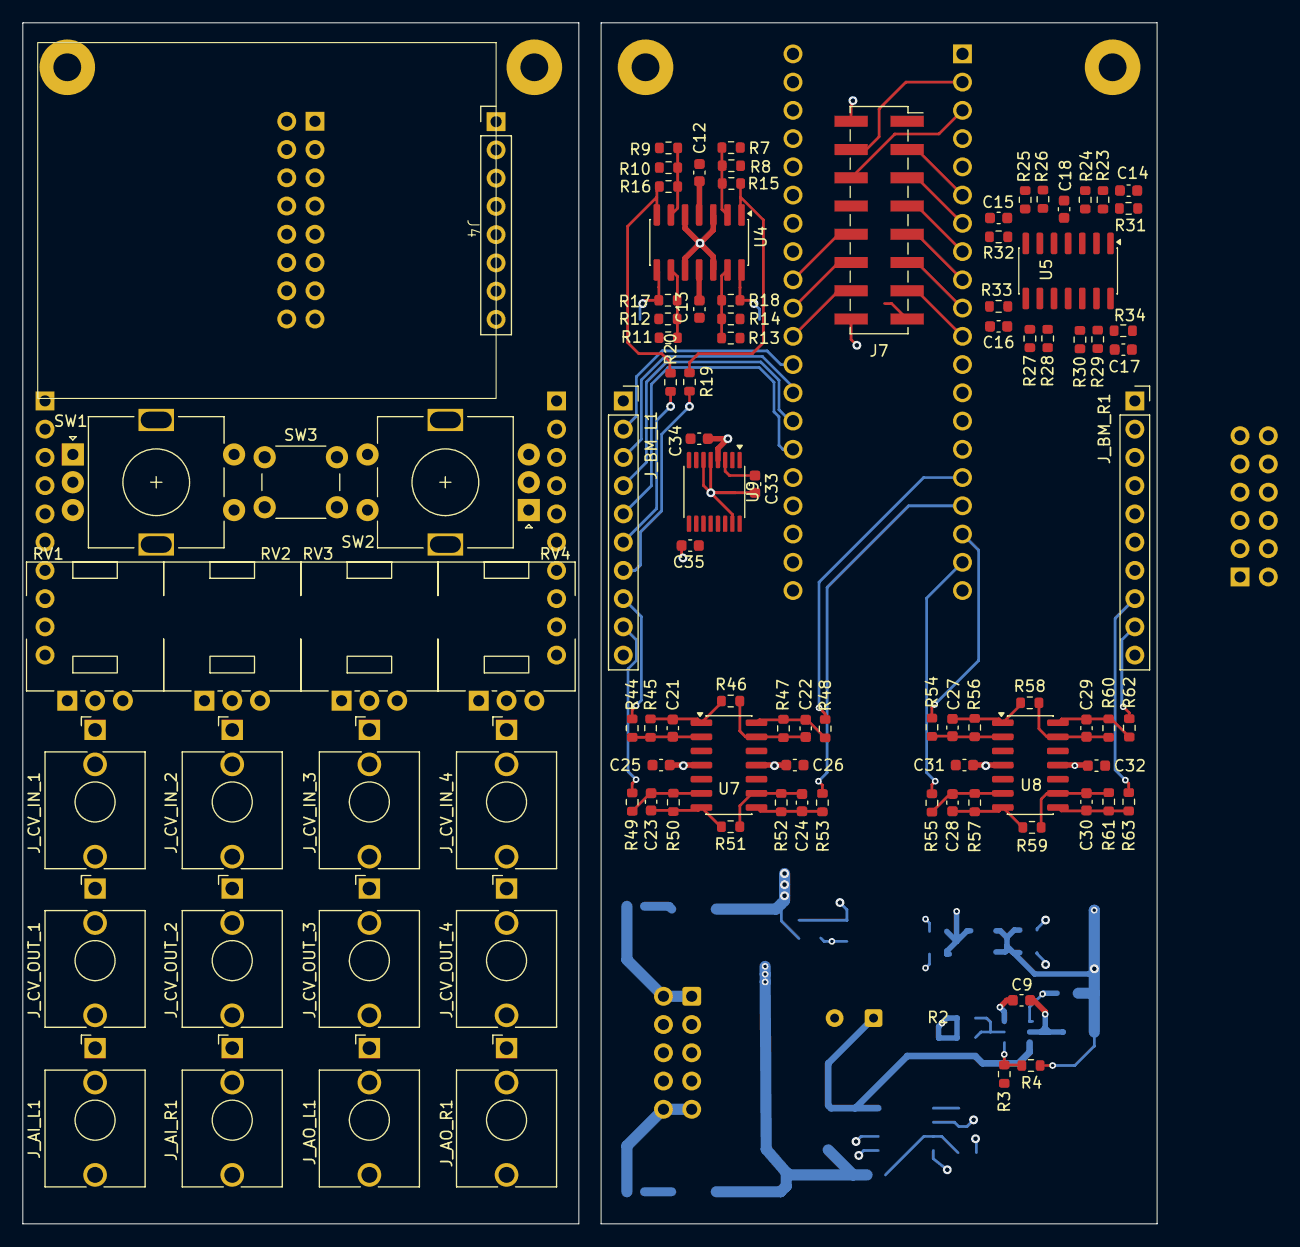
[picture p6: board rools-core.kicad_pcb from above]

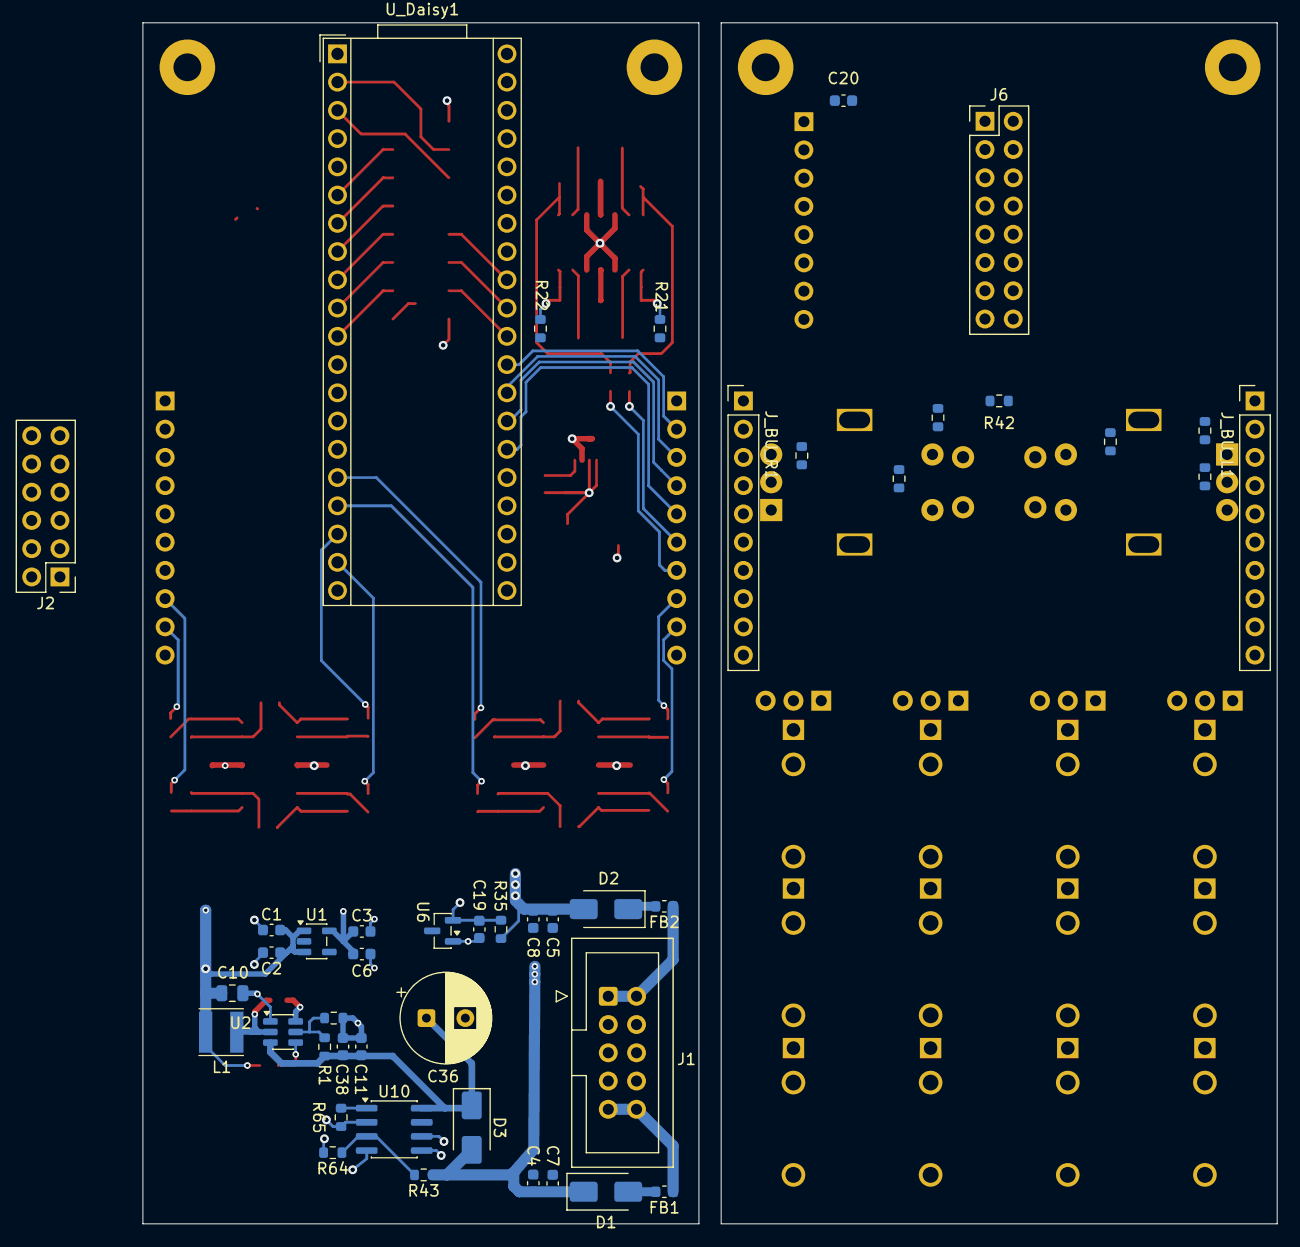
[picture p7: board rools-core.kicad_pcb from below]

Board: 4 copper layers, 102.0 x 108.0 mm, 144 parts (45 on the bottom side), 98 nets.

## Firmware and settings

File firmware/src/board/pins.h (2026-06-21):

#pragma once

#include "daisy_seed.h"

// Rools Core Seed map — 2026-06 定稿（见 docs/04-hardware-architecture.md）

namespace rools {
namespace pins {

using Pin = daisy::Pin;

// D0 / pin 1 — EXP_GPIO0（USB_HS_ID，P2 pin 15）

// Enc A — D1–D3, Seed pins 2–4
constexpr Pin kEncA_A  = daisy::seed::D1;
constexpr Pin kEncA_B  = daisy::seed::D2;
constexpr Pin kEncA_Sw = daisy::seed::D3;

// Btn + ST7735 SPI — D4–D10, Seed pins 5–11
constexpr Pin kBtnCenter = daisy::seed::D4;
constexpr Pin kLcdBlk    = daisy::seed::D5;
constexpr Pin kLcdRst    = daisy::seed::D6;
constexpr Pin kLcdCs     = daisy::seed::D7;
constexpr Pin kLcdSck    = daisy::seed::D8;  // SPI1_SCK — 亦接 DAC8565
constexpr Pin kLcdDc     = daisy::seed::D9;
constexpr Pin kLcdMosi   = daisy::seed::D10; // SPI1_MOSI — 亦接 DAC8565

// D11–D12 / pin 12–13 — I2C1 → P2 EXP_BUS（SCL/SDA）

// Exp MIDI — D13–D14, Seed pins 14–15, USART1
constexpr Pin kMidiTx = daisy::seed::D13;
constexpr Pin kMidiRx = daisy::seed::D14;

// DAC8565 CV Out — D26–D27, Seed pins 33–34
constexpr Pin kDacCs   = daisy::seed::D26; // DAC_CS / SYNC
constexpr Pin kDacLdac = daisy::seed::D27; // DAC_LDAC

// CV in — D15–D18, Seed pins 22–25, ADC0–3
constexpr Pin kCv1Adc = daisy::seed::D15;
constexpr Pin kCv2Adc = daisy::seed::D16;
constexpr Pin kCv3Adc = daisy::seed::D17;
constexpr Pin kCv4Adc = daisy::seed::D18;

// Knob — D19–D22, Seed pins 26–29, ADC4–7
constexpr Pin kKnob1Adc = daisy::seed::D19;
constexpr Pin kKnob2Adc = daisy::seed::D20;
constexpr Pin kKnob3Adc = daisy::seed::D21;
constexpr Pin kKnob4Adc = daisy::seed::D22;

// Enc B — D23–D25, Seed pins 30–32
constexpr Pin kEncB_A  = daisy::seed::D23;
constexpr Pin kEncB_B  = daisy::seed::D24;
constexpr Pin kEncB_Sw = daisy::seed::D25;

// D28 / pin 35 — net EXTI_PWR（LM393 掉电检测，见 ADR-015）
constexpr Pin kPwrFail = daisy::seed::D28;

} // namespace pins
} // namespace rools

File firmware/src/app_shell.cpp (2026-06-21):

#include "app_shell.h"

#include "apps/app_registry.h"
#include "board/cv_calibration.h"
#include "board/cv_out.h"
#include "board/cv_reference.h"
#include "board/pins.h"
#include "board/spi1_bus.h"
#include "daisy_seed.h"
#include "display/gfx.h"
#include "display/st7735.h"
#include "board/enc_debug.h"
#include "hid/encoder.h"
#include "hid/switch.h"
#include "settings/settings_store.h"
#include "ui/app_menu_view.h"
#include "ui/layout_view.h"

namespace rools {

using namespace daisy;

// 文件作用域外设；init() 前不可用
static DaisySeed   hw;
static AppShell*   shell_instance = nullptr; // ISR → process_audio 桥接
static St7735      display;
static Gfx         gfx(display);
static LayoutView  layout_view(gfx);
static Encoder     enc_a;
static Encoder     enc_b;
static Switch      btn_center;
static volatile int32_t enc_a_delta_accum  = 0;
static volatile int32_t enc_b_delta_accum  = 0;
static volatile uint8_t enc_a_press_events = 0; // bit0 rise, bit1 fall
static volatile uint8_t enc_b_press_events = 0; // bit0 rise, bit1 fall
static volatile uint8_t btn_events         = 0; // bit0 rise, bit1 fall
static constexpr uint8_t kEventRise        = 0x01;
static constexpr uint8_t kEventFall        = 0x02;
static constexpr size_t kAdcChannelCount = 8;
static AdcChannelConfig adc_cfg[kAdcChannelCount];
static CvReferenceConfig g_cv_cfg[kCvChannelCount];
static CvOutDriver       cv_out_drv;

static void LoadCvConfigFromSettings()
{
    GlobalSettings& s = SettingsStore::Instance().Get();
    for(size_t i = 0; i < kCvChannelCount; ++i)
        g_cv_cfg[i] = CvCalToConfig(s.cv[i]);
}

static void PersistLastApp(size_t index)
{
    GlobalSettings& s = SettingsStore::Instance().Get();
    if(s.last_app_index != static_cast<uint32_t>(index))
    {
        s.last_app_index = static_cast<uint32_t>(index);
        SettingsStore::Instance().MarkDirty();
    }
}

static void AudioCallback(AudioHandle::InputBuffer  in,
                          AudioHandle::OutputBuffer out,
                          size_t                    size)
{
    enc_a.Debounce();
    enc_b.Debounce();
    btn_center.Debounce();

    enc_a_delta_accum += enc_a.Increment();
    enc_b_delta_accum += enc_b.Increment();

    if(enc_a.RisingEdge())
        enc_a_press_events |= kEventRise;
    if(enc_a.FallingEdge())
        enc_a_press_events |= kEventFall;
    if(enc_b.RisingEdge())
        enc_b_press_events |= kEventRise;
    if(enc_b.FallingEdge())
        enc_b_press_events |= kEventFall;
    if(btn_center.RisingEdge())
        btn_events |= kEventRise;
    if(btn_center.FallingEdge())
        btn_events |= kEventFall;

    if(shell_instance)
    {
        // CV 与 Knob 为独立 ADC 通道；AppShell 只采集/标定，列用途由各 App 决定（见 ParamMap）。
        for(size_t i = 0; i < kCvChannelCount; ++i)
        {
            // columns[i] 仅按硬件索引 i 对齐 CVi + KNOBi，无固定参数语义
            const float cv_uni   = hw.adc.GetFloat(static_cast<int>(i));
            const float knob_uni = hw.adc.GetFloat(static_cast<int>(kCvChannelCount + i));
            const float cv       = CvAdcToNormalized(cv_uni, g_cv_cfg[i]);
            shell_instance->columns[i].knob = knob_uni; // 0..1，App 自选是否使用
            shell_instance->columns[i].cv   = cv;       // -1..1，App 自选是否使用
            shell_instance->columns[i].sum  = ColumnSumNormalized(cv, knob_uni); // 便捷合成；App 可改用 knob/cv 分别读
        }
    }

    if(shell_instance)
        shell_instance->process_audio(in[0], in[1], out[0], out[1], size);
}

void AppShell::init()
{
    shell_instance = this;

    hw.Init();

    adc_cfg[0].InitSingle(pins::kCv1Adc);
    adc_cfg[1].InitSingle(pins::kCv2Adc);
    adc_cfg[2].InitSingle(pins::kCv3Adc);
    adc_cfg[3].InitSingle(pins::kCv4Adc);
    adc_cfg[4].InitSingle(pins::kKnob1Adc);
    adc_cfg[5].InitSingle(pins::kKnob2Adc);
    adc_cfg[6].InitSingle(pins::kKnob3Adc);
    adc_cfg[7].InitSingle(pins::kKnob4Adc);
    hw.adc.Init(adc_cfg, kAdcChannelCount);
    hw.adc.Start();

    SettingsStore::Instance().Init(hw.qspi);
    LoadCvConfigFromSettings();

    Spi1Bus::InitDefault();
    display.Init();
    SettingsStore::InitPowerFailDetection();

    enc_a.Init(pins::kEncA_A, pins::kEncA_B, pins::kEncA_Sw);
    enc_b.Init(pins::kEncB_A, pins::kEncB_B, pins::kEncB_Sw);
    btn_center.Init(pins::kBtnCenter);

    cv_out_drv.Init();
    cv_out       = CvOutputs{0.f, 0.f, 0.f, 0.f};

    AppRegistry::BindUi(&gfx);

    size_t boot_index = SettingsStore::Instance().Get().last_app_index;
    if(boot_index >= AppRegistry::Count())
        boot_index = 0;
    load_app(boot_index); // boot 进入上次 app；运行时切换用 request_app_switch()

    hw.StartAudio(AudioCallback);
}

void AppShell::run_forever()
{
    uint32_t last_ui_ms = System::GetNow();
    bool     last_menu_open = false;
    layout_view.ResetCache();

    while(true)
    {
        int32_t da = 0;
        int32_t db = 0;
        uint8_t a_events = 0;
        uint8_t b_events = 0;
        uint8_t c_events = 0;

        __disable_irq();
        da                 = enc_a_delta_accum;
        db                 = enc_b_delta_accum;
        a_events           = enc_a_press_events;
        b_events           = enc_b_press_events;
        c_events           = btn_events;
        enc_a_delta_accum  = 0;
        enc_b_delta_accum  = 0;
        enc_a_press_events = 0;
        enc_b_press_events = 0;
        btn_events         = 0;
        __enable_irq();

        const uint32_t now = System::GetNow();
        SettingsStore::Instance().Tick(now);
        bool           ui_dirty = false;

        const GestureFrameInput gesture_input{
            now, da, db, a_events, b_events, c_events, btn_center.Pressed(), enc_a.Pressed()};
        const GestureFrameResult gesture_result = gesture_controller_.Update(gesture_input);
        ui_dirty |= gesture_result.ui_dirty;

        const MenuUpdateInput menu_input{now,
                                         enc_a.Pressed(),
                                         AppRegistry::Count(),
                                         current_index_,
                                         gesture_result.events,
                                         gesture_result.count};
        const MenuResult menu_result = app_menu_view_.Update(menu_input);
        ui_dirty |= menu_result.ui_dirty;
        if(last_menu_open != menu_result.menu_open)
        {
            layout_view.ResetCache();
            ui_dirty       = true;
            last_menu_open = menu_result.menu_open;
        }
        if(menu_result.request_switch)
            request_app_switch(menu_result.switch_index);

        if(!menu_result.consumed)
            RouteInputToCurrentApp(gesture_result, ui_dirty);

        InputDebugUpdate(static_cast<int>(da),
                         static_cast<int>(db),
                         a_events,
                         b_events,
                         c_events,
                         enc_a.Pressed(),
                         enc_b.Pressed(),
                         btn_center.Pressed());
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

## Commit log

2026-06-13 Enable M1 firmware build with libDaisy and IDE config.
    Wire up Makefile and AppShell audio passthrough so the project compiles, and add shared editor settings for libDaisy headers outside the repo.
2026-06-13 Add build script for submodules, libs, firmware, and optional IDE db.
    Single entry point runs the full compile chain and generates compile_commands.json when compiledb is installed.
2026-06-14 Add M1 spectrum firmware with ST7735 display and FFT analyzer.
    Wire AppShell to encoders, spectrum app, and IDE compile-db sanitization for macOS clang.
2026-06-14 Document firmware framework lifecycle and app registration.
    Clarify App/AppShell thread model, main loop structure, and how to add apps via AppRegistry.
2026-06-14 Add MFX-style app switching plan and unify audio at 48 kHz.
    Document crossfade/DSP pool design, stub AppShell switch APIs, and centralize kAudioSampleRate in board/audio_config.h.
2026-06-14 Pin libDaisy v8.1.0 and DaisySP V1.0.0 submodules.
    Document pinned dependency tags in README for reproducible builds.
2026-06-14 Document M2 engineering constraints in ADR-011 through ADR-014.
    Cover Buck power, SPI DMA, mechanical depth, 4-layer PCB, and normalled jack wiring across specs and roadmap.
2026-06-14 Add M2 KiCad rools-core project and regroup Seed pin map for PCB routing.
    Introduce hierarchical Power/Seed/Audio/CV/UI schematics with Patch symbol library, and align pins.h so encoders, LCD, and CV ADCs use contiguous Seed pins.
    [audio.kicad_sch, cv.kicad_sch, power.kicad_sch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]
2026-06-14 Wire rools-core KiCad sheets with global labels and UI peripherals.
    Migrate inter-sheet nets to global labels and flesh out UI, power, and
    child-sheet power entry so net names align with pins.h for PCB routing.
    [audio.kicad_sch, cv.kicad_sch, power.kicad_sch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]
2026-06-17 Fix encoder sampling in audio ISR and add display test firmware.
    Move input Debounce to AudioCallback with interrupt accumulate and main-loop consume so UI SPI refresh cannot drop encoder steps, and add ST7735S tuning, midnight theme, and a default DisplayTest app with toggleable on-screen input debug.
    [app_shell.cpp]
2026-06-18 Refactor app input handling with gesture-controller pipeline.
    Decouple raw edge parsing from AppShell by introducing standardized gesture events, route menu/app input via gesture frames, and sync Shift interaction rules in UX/ADR docs.
2026-06-19 Add oscilloscope app and bottom-bar UI architecture.
    This introduces the oscilloscope feature, replaces legacy hint/menu controller components with the new layout views, and updates display pipeline primitives to support the new UI rendering flow.
    [app_shell.cpp]
2026-06-19 Refine scope parameter model and rendering behavior for modular workflows.
    This aligns time/voltage and trigger controls with instrument-style operation while documenting AC-coupled audio-input limits for reliable CV interpretation.
2026-06-20 Add CV reference calibration and refine oscilloscope app rendering.
    Introduce board/cv_reference for ADC-to-eurorack-volt mapping, calibrated
    against measured CV front-end (center 1.096V, atten 0.1043 with grounds tied).
2026-06-20 Add QSPI settings persistence, CV calibration app, and CV output driver.
    [audio.kicad_sch, cv.kicad_sch, power.kicad_sch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]
2026-06-20 Align Core with onboard audio and split CV/Knob ADC architecture.
    Document Seed pin16–19 + TL074 (no PCM3060), 8-way ADC firmware synthesis, Enc/Knob pin remap, EXTI_PWR on D28, and update KiCad seed/CV/audio sheets accordingly.
    [audio.kicad_sch, cv.kicad_sch, seed.kicad_sch]
2026-06-21 Sync Core schematic Rev 0.2 with docs and firmware.
    Align DAC8565/OPA4171 CV path (2.5V internal ref, 12.5k/100k), LM393 power-fail hold-up, and SPI1 CV driver fixes (LDAC polarity, debounced save with backlight off).
    [audio.kicad_sch, cv.kicad_sch, power.kicad_sch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]
2026-06-21 Finalize Core schematic pin map and JLC BOM for assembly.
    MIDI USART1 on D13/D14, DAC8565 on D26/D27, and document P2 EXP_BUS so Exp I/O no longer conflicts with CV Out.
    [audio.kicad_sch, cv.kicad_sch, power.kicad_sch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]
2026-06-21 Use Patch ENCODERNOSILK symbols for EC11 encoders on UI sheet.
    [cv.kicad_sch, ui.kicad_sch]
2026-06-21 Lay out Core front-panel PCB for 10HP Eurorack fit.
    Use RK09L 3-pin no-MP pots, split Daisy daughterboard, audio jack refs, and local display footprint library.
    [audio.kicad_sch, cv.kicad_sch, power.kicad_sch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]
2026-06-22 Route Core PCB and place Daisy Seed on the daughterboard.
    Sync schematic sheets with the split-board layout and updated interconnects.
    [audio.kicad_sch, cv.kicad_sch, power.kicad_sch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]
2026-06-24 Remove Patch reference assets and continue Core PCB routing.
    Drop imported Patch symbols, local display footprint, and stale BOM CSV while advancing layout and schematic interconnects.
    [cv.kicad_sch, power.kicad_sch, rools-core.csv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]
2026-06-24 Align seed schematic with Electrosmith Daisy module footprint.
    Update power and UI interconnects and continue Core PCB layout after removing the local footprint library.
    [power.kicad_sch, rools-core.kicad_pcb, seed.kicad_sch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]
2026-06-25 Continue Core PCB routing and tune board design rules.
    Fix seed debug header to 1x10 and add preset track/via widths for layout work.
    [rools-core.kicad_pcb, seed.kicad_sch]
